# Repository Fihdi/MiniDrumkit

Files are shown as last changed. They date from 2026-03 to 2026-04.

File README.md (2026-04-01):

# 30hp Drumkit module
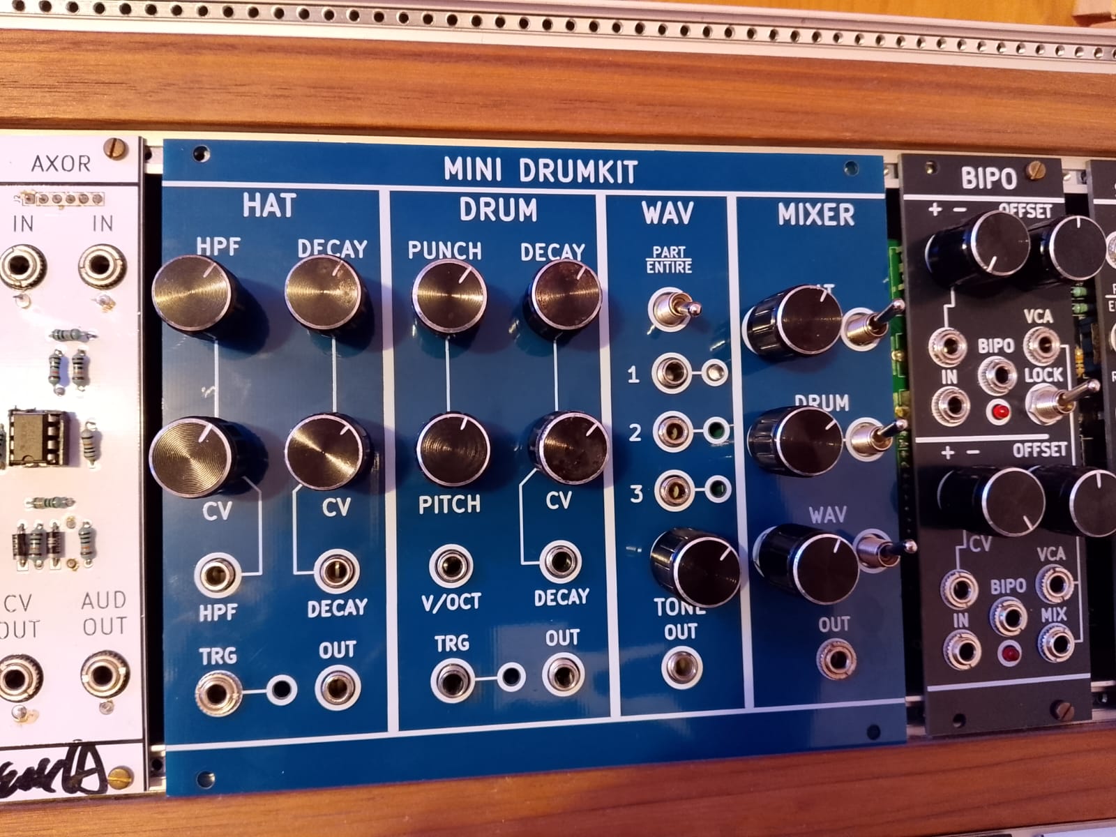
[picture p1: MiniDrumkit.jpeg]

Eurorack DrumKit module with an Arduino Nano ESP32 3 channel wave-file player and analog Hi-Hat and Kick Drum sections.

The WAV Files are read from a microSD card and need to be called "1.wav", "2.wav" and "3.wav". The files need to be mono, encoded in 16-bit and have 16kHz sampling rate. You can use Audacity to export wav files in this format.

Demo Video: https://www.youtube.com/watch?v=cPHg9nKNO_o

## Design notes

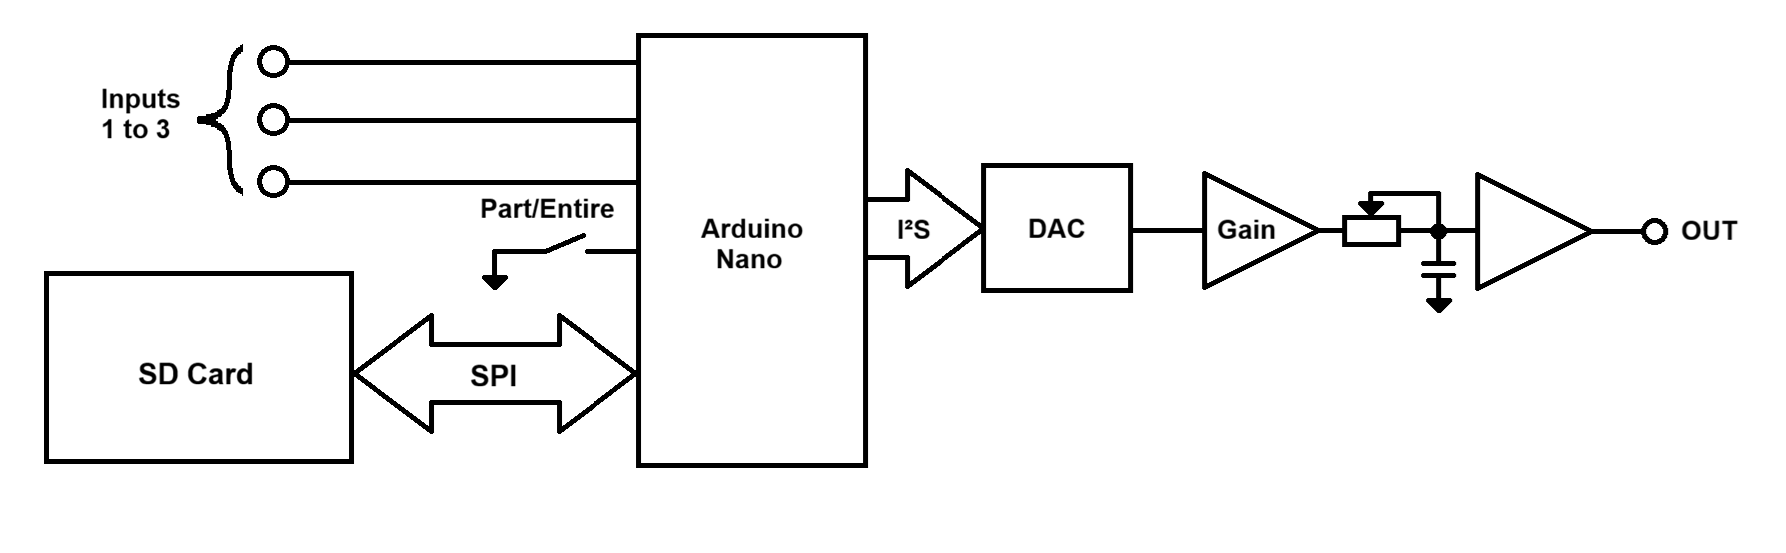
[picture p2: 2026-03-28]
MiniDrumkit2/WAVPlayer-BLOCK.png

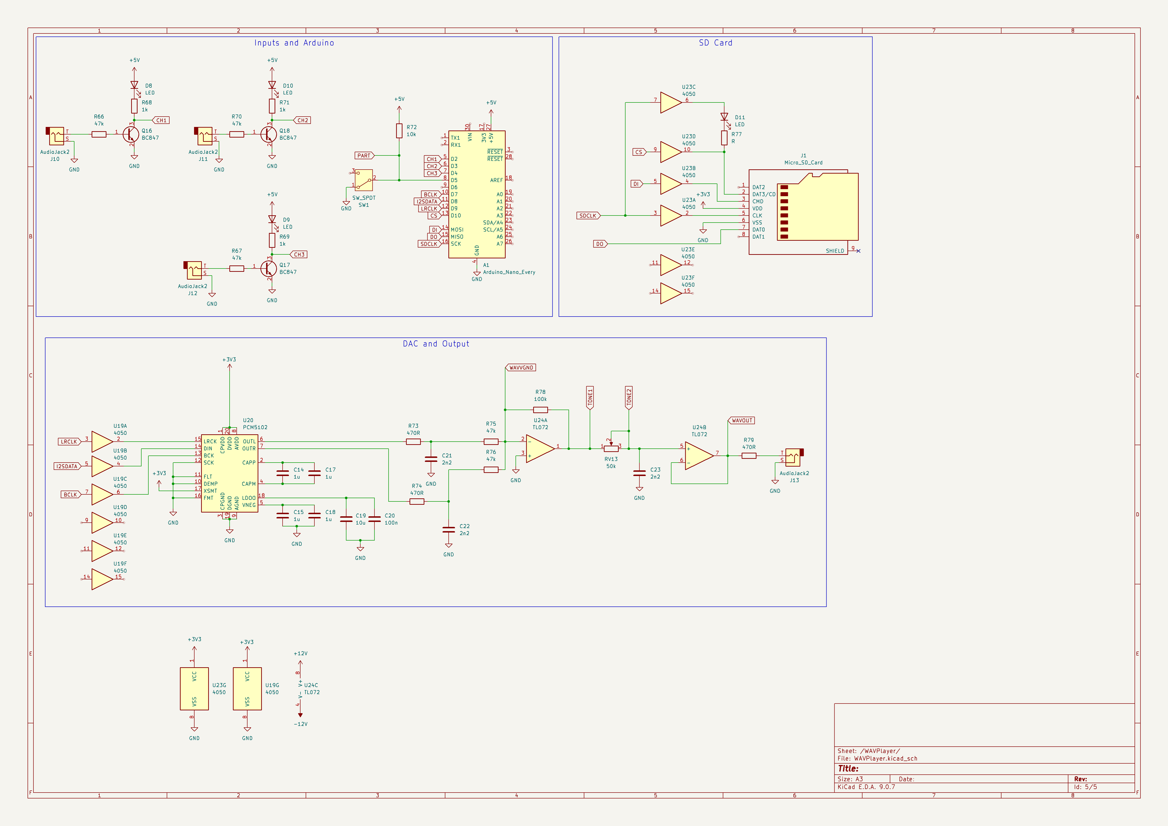
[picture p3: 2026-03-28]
MiniDrumkit2/DAC.png

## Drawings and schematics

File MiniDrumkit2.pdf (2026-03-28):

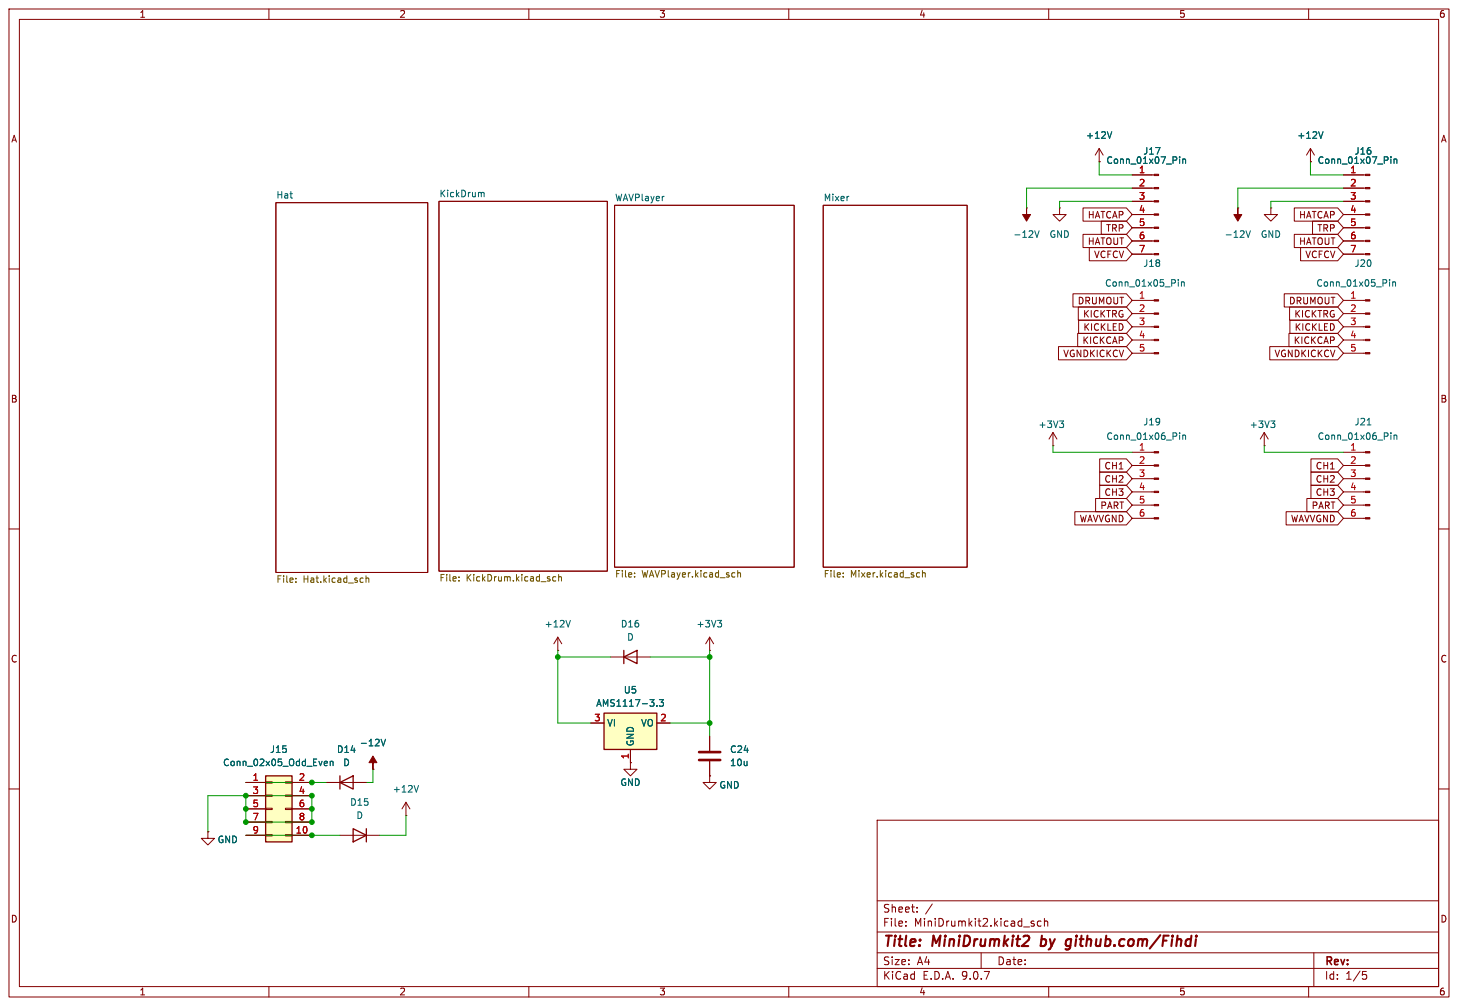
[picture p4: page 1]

5 5 | 6 6
7 7 | 8 8

Id: 1/5 Title: MiniDrumkit2 by github.com/Fihdi File: MiniDrumkit2.kicad_sch Sheet: /

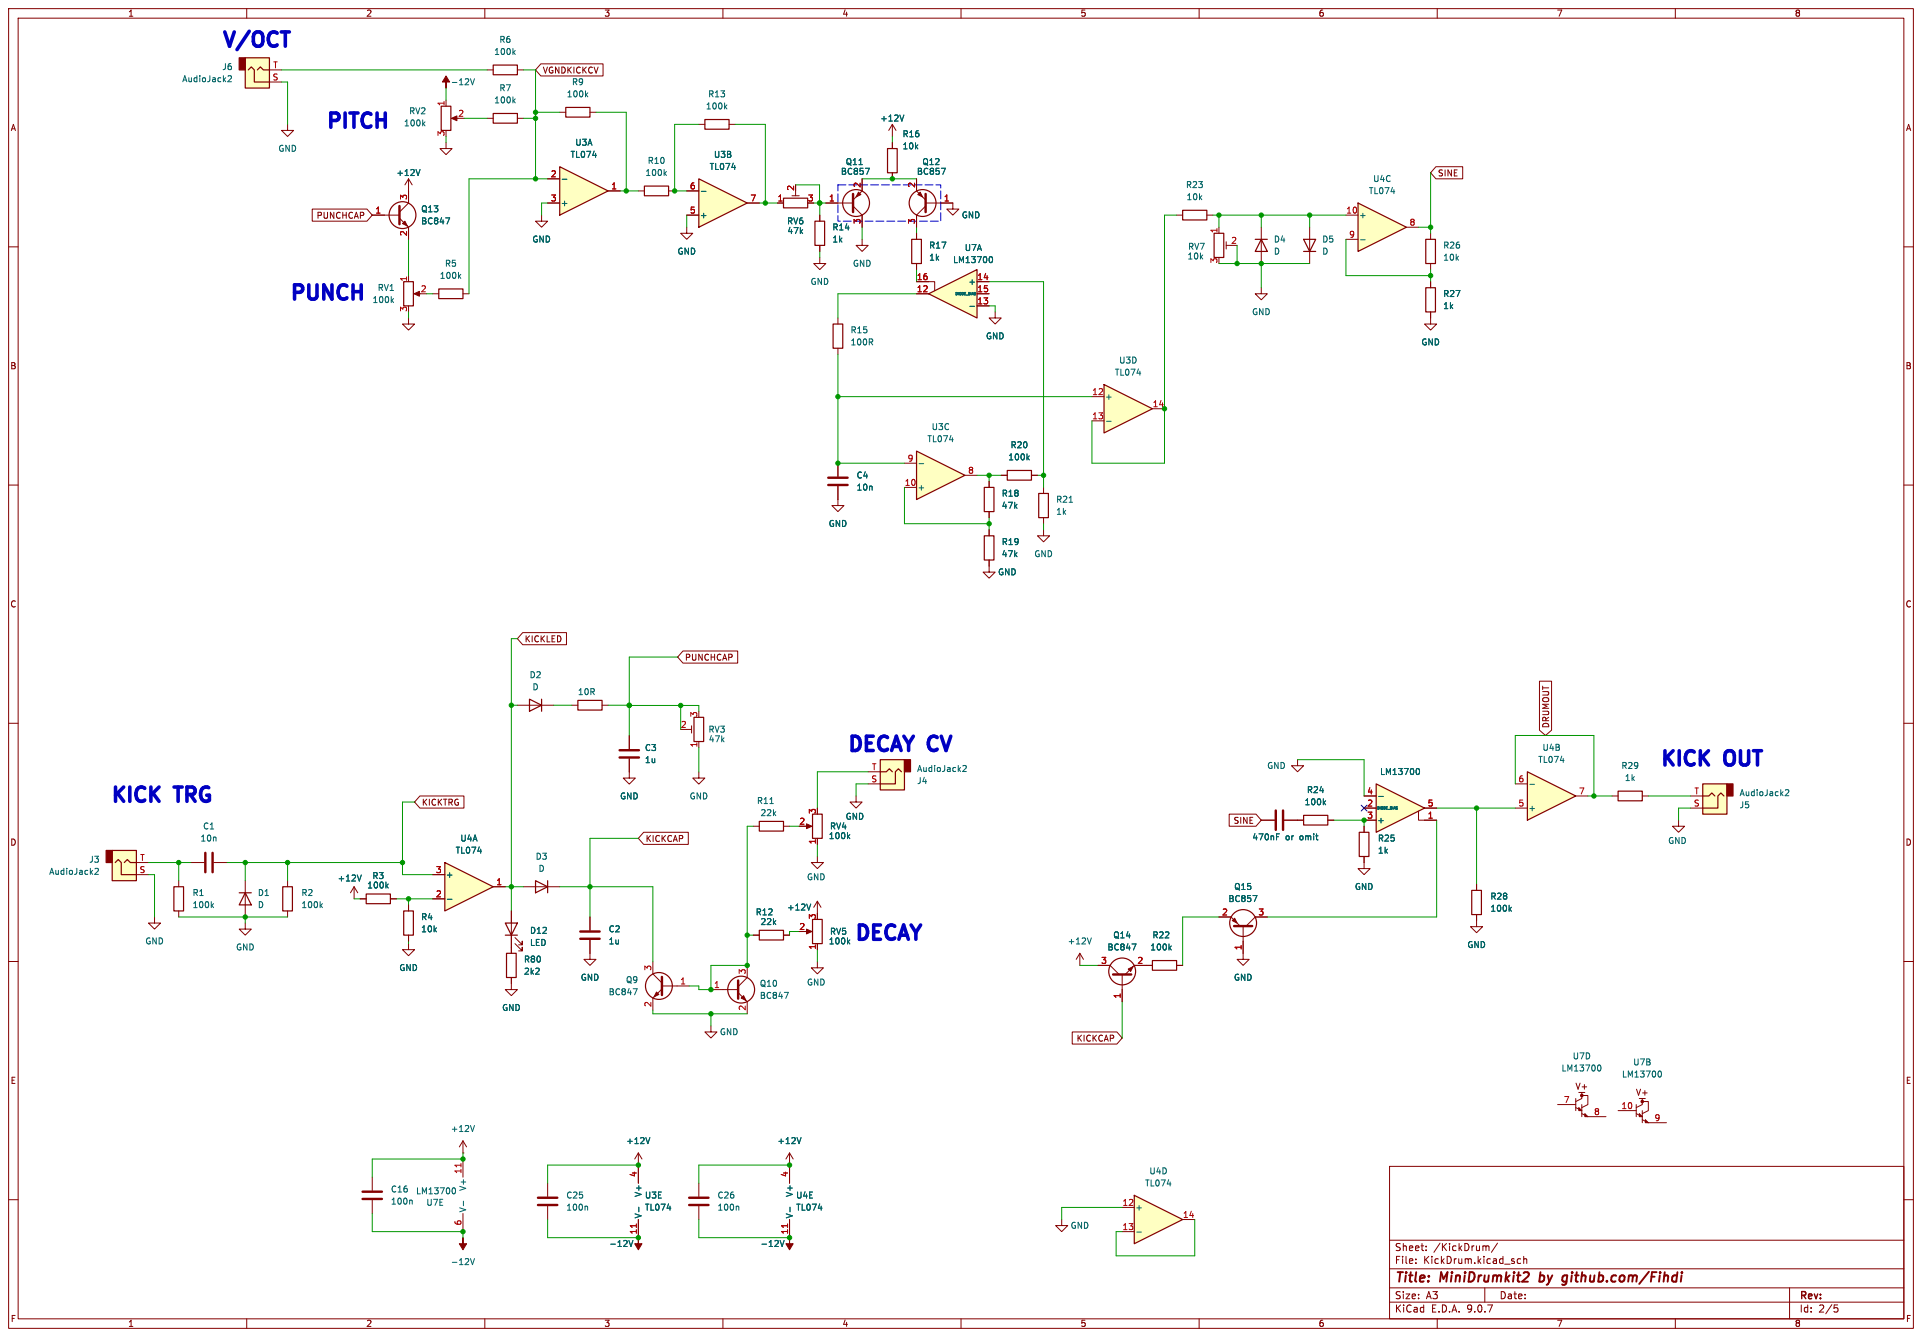
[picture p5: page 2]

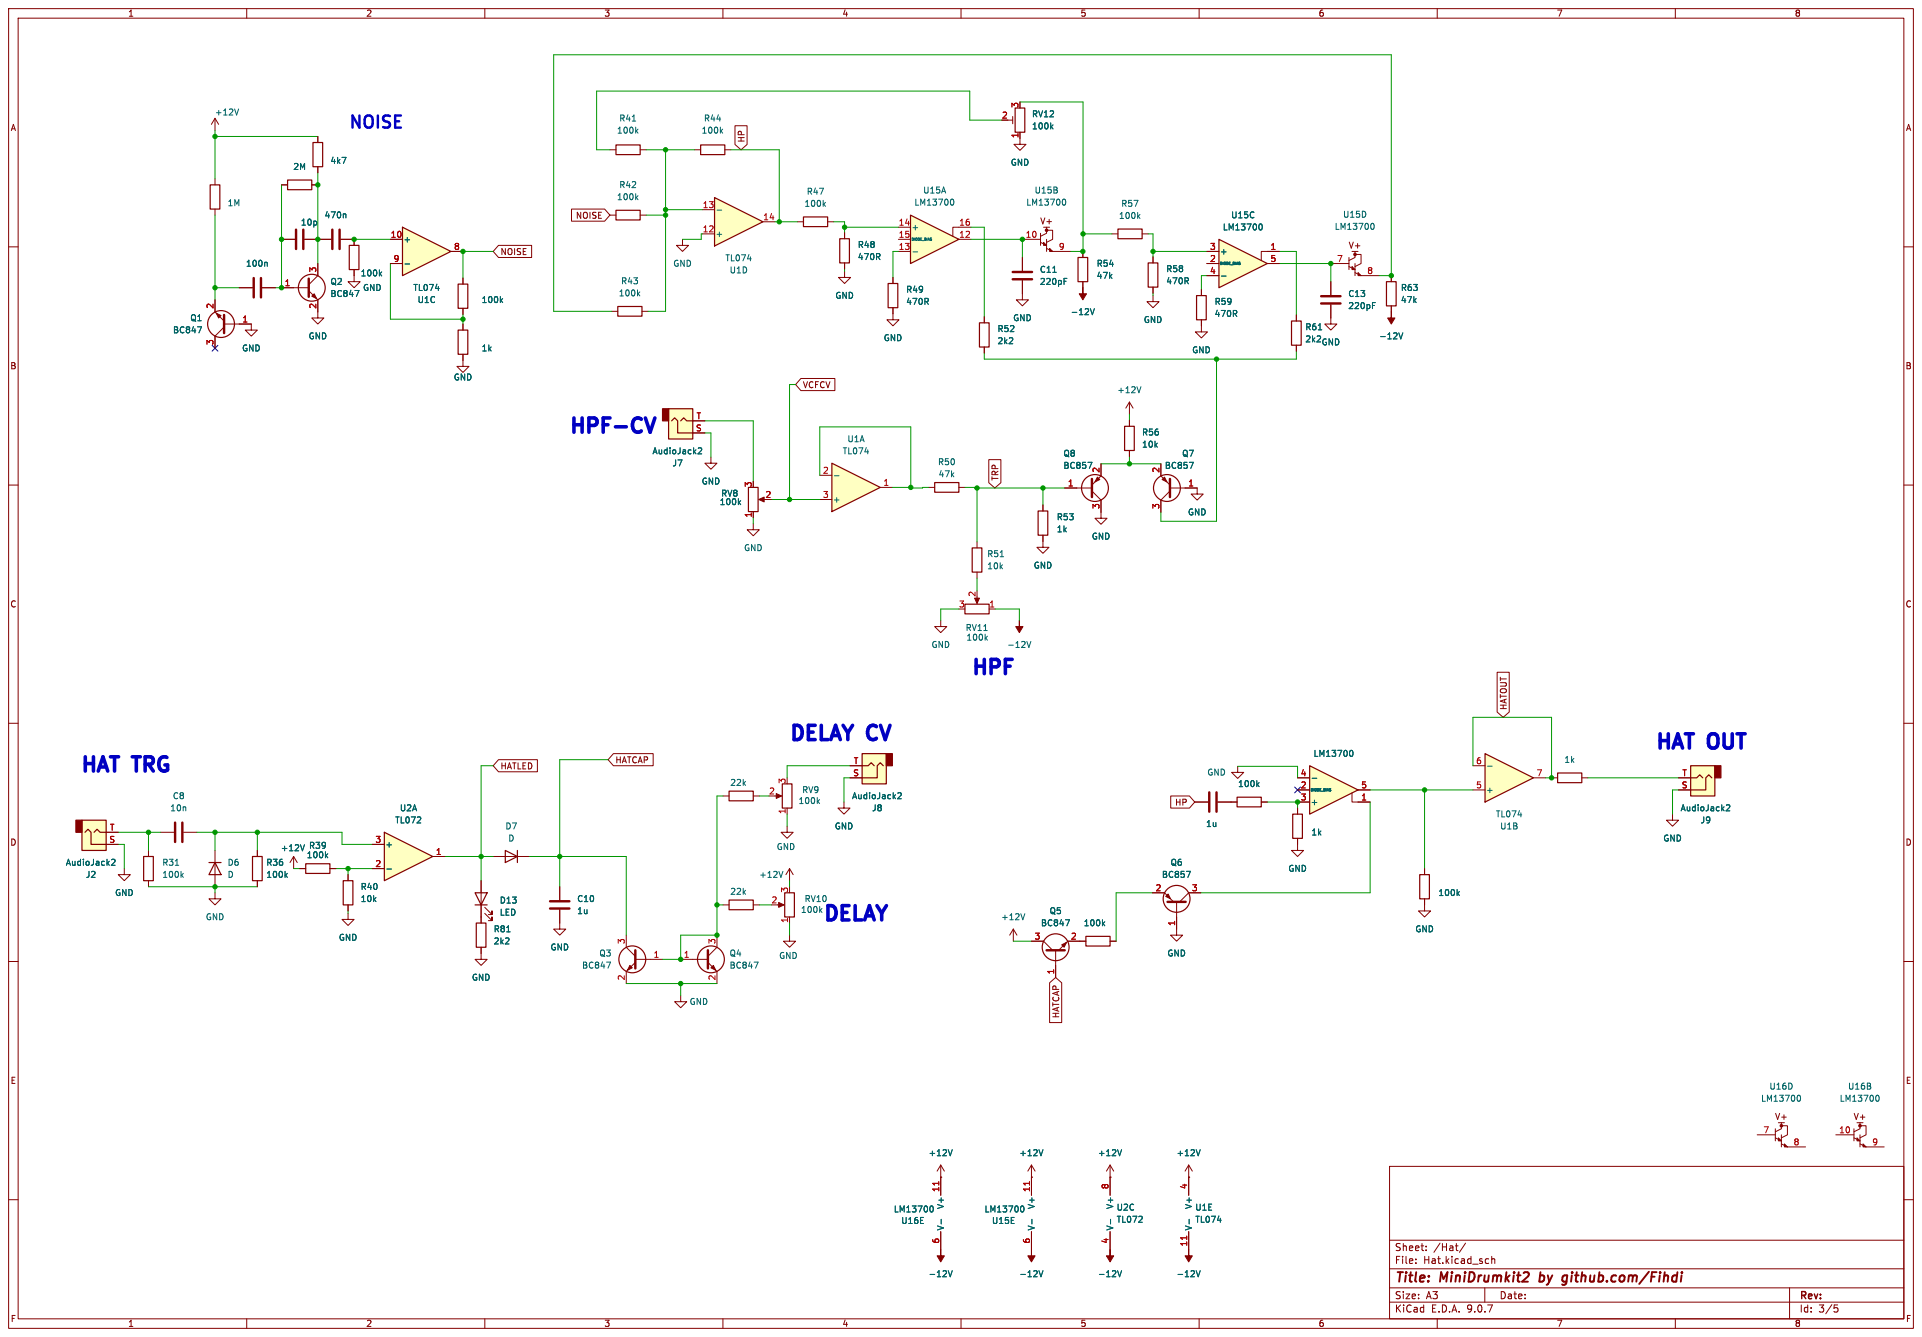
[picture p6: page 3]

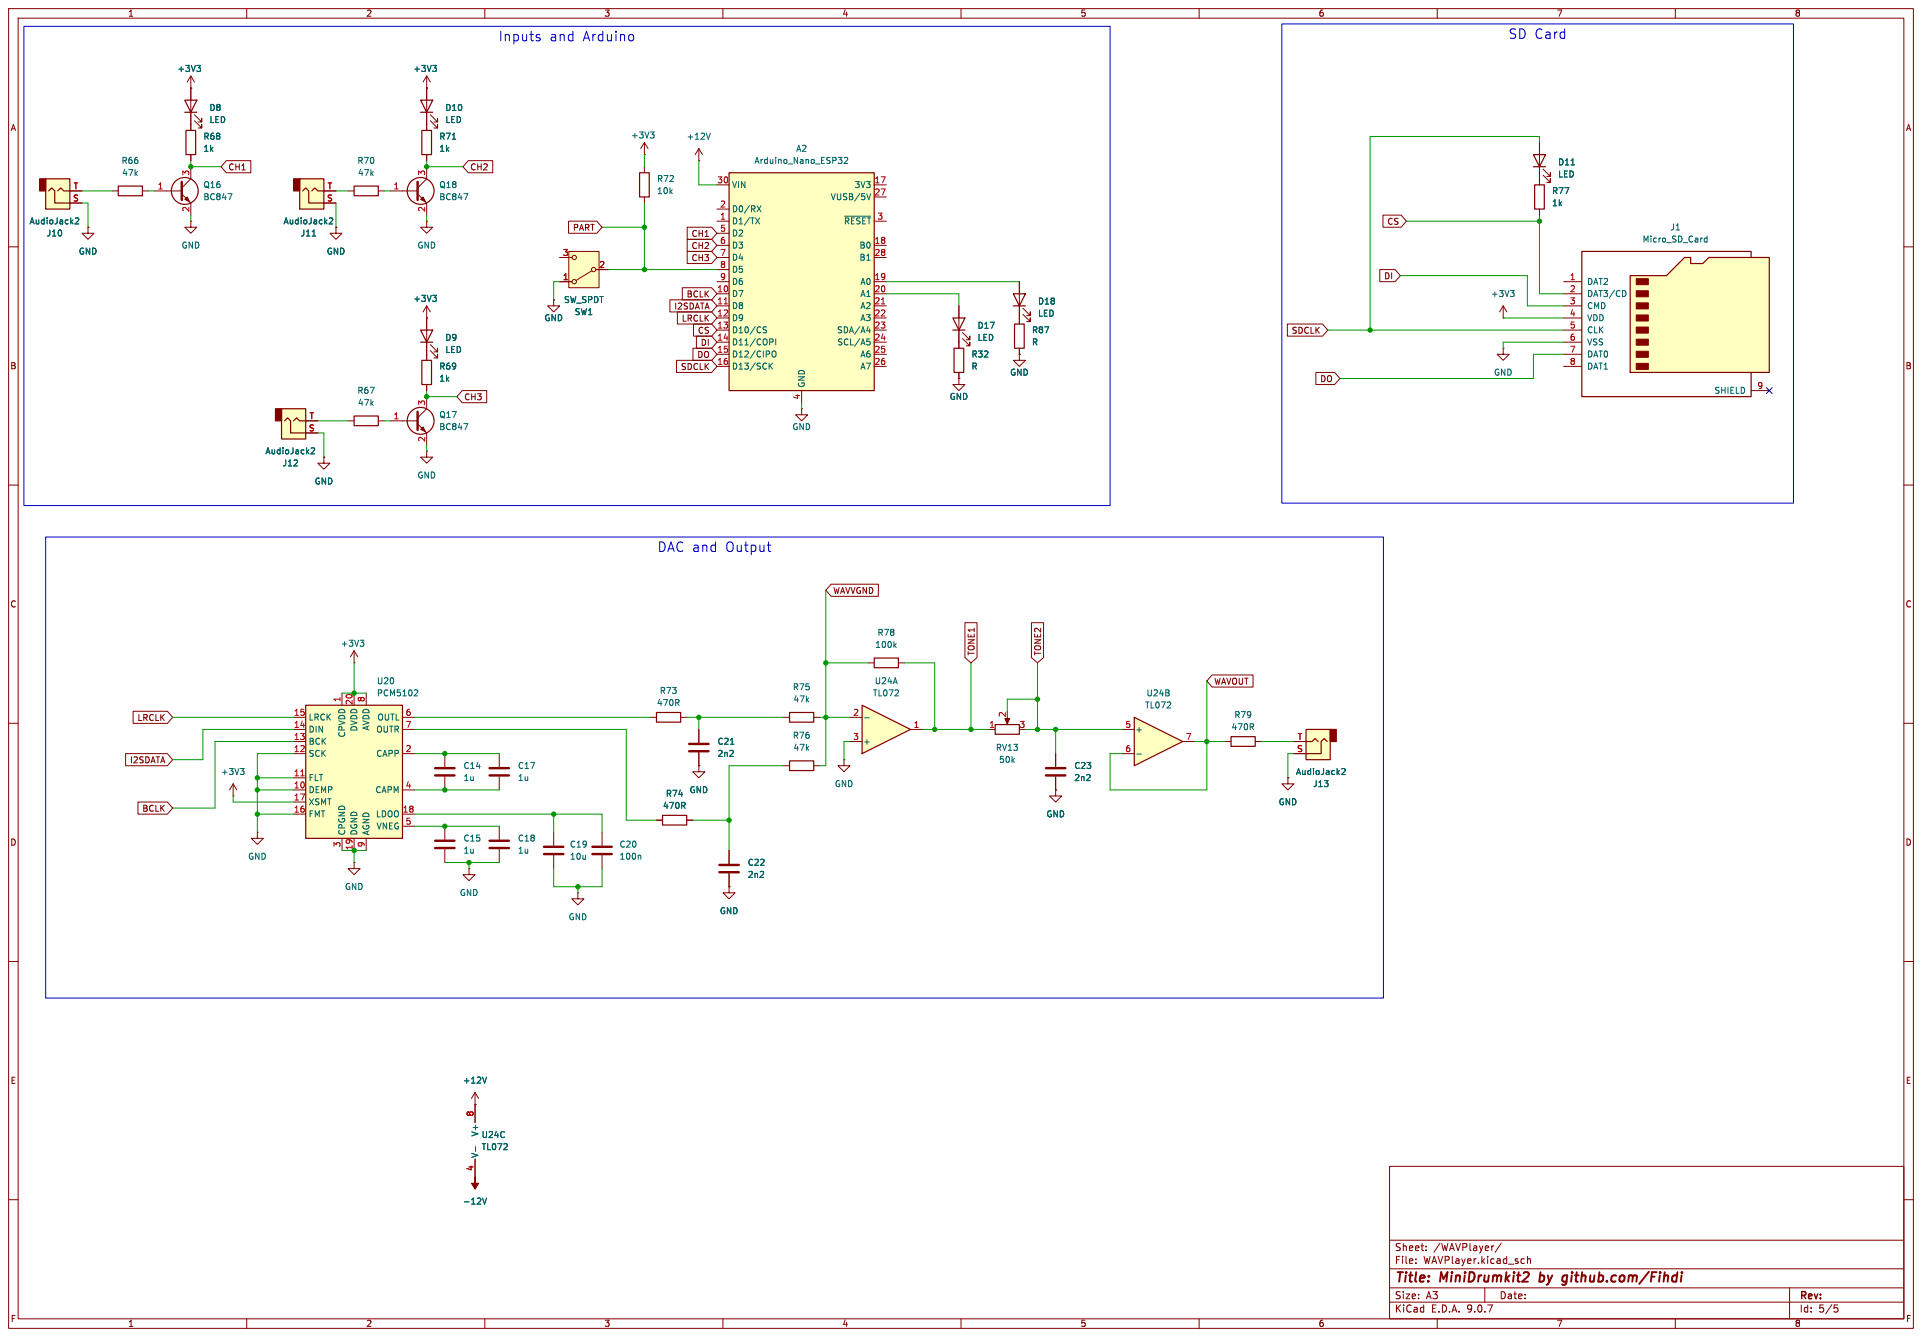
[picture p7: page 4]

9 OUTL 6 OUTR 7 CAPP 2 CAPM 4

Id: 5/5 Title: MiniDrumkit2 by github.com/Fihdi File: WAVPlayer.kicad_sch Sheet: /WAVPlayer/

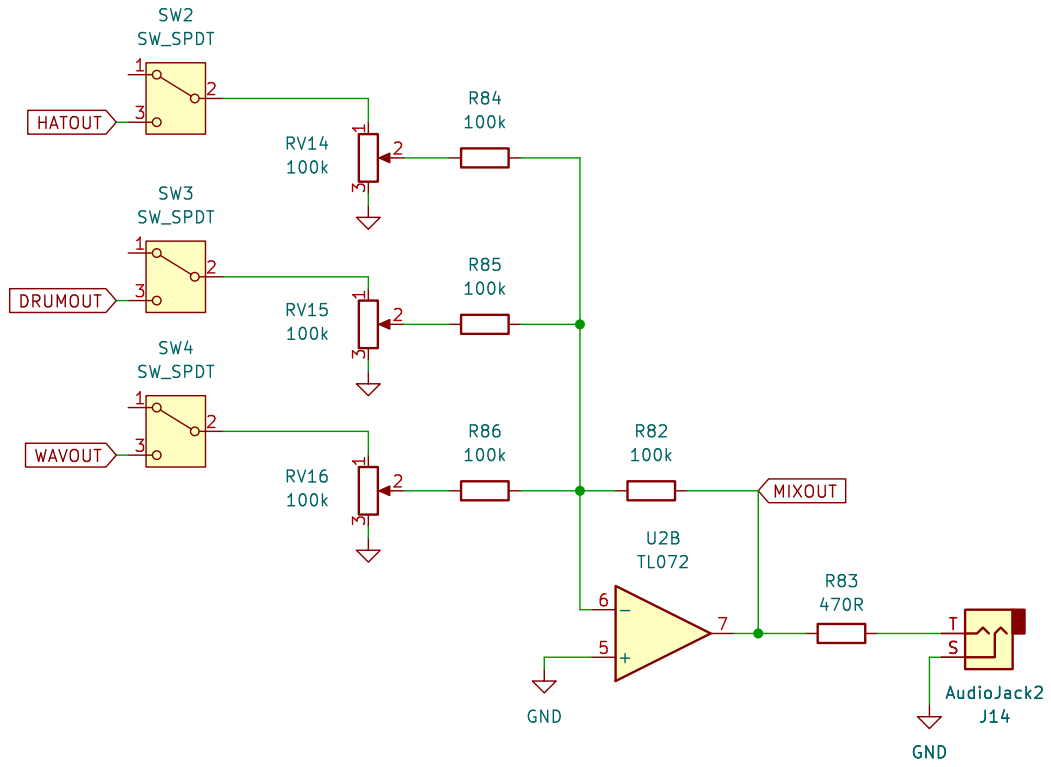
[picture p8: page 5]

Id: 5/5 Title: MiniDrumkit2 by github.com/Fihdi File: Mixer.kicad_sch Sheet: /Mixer/

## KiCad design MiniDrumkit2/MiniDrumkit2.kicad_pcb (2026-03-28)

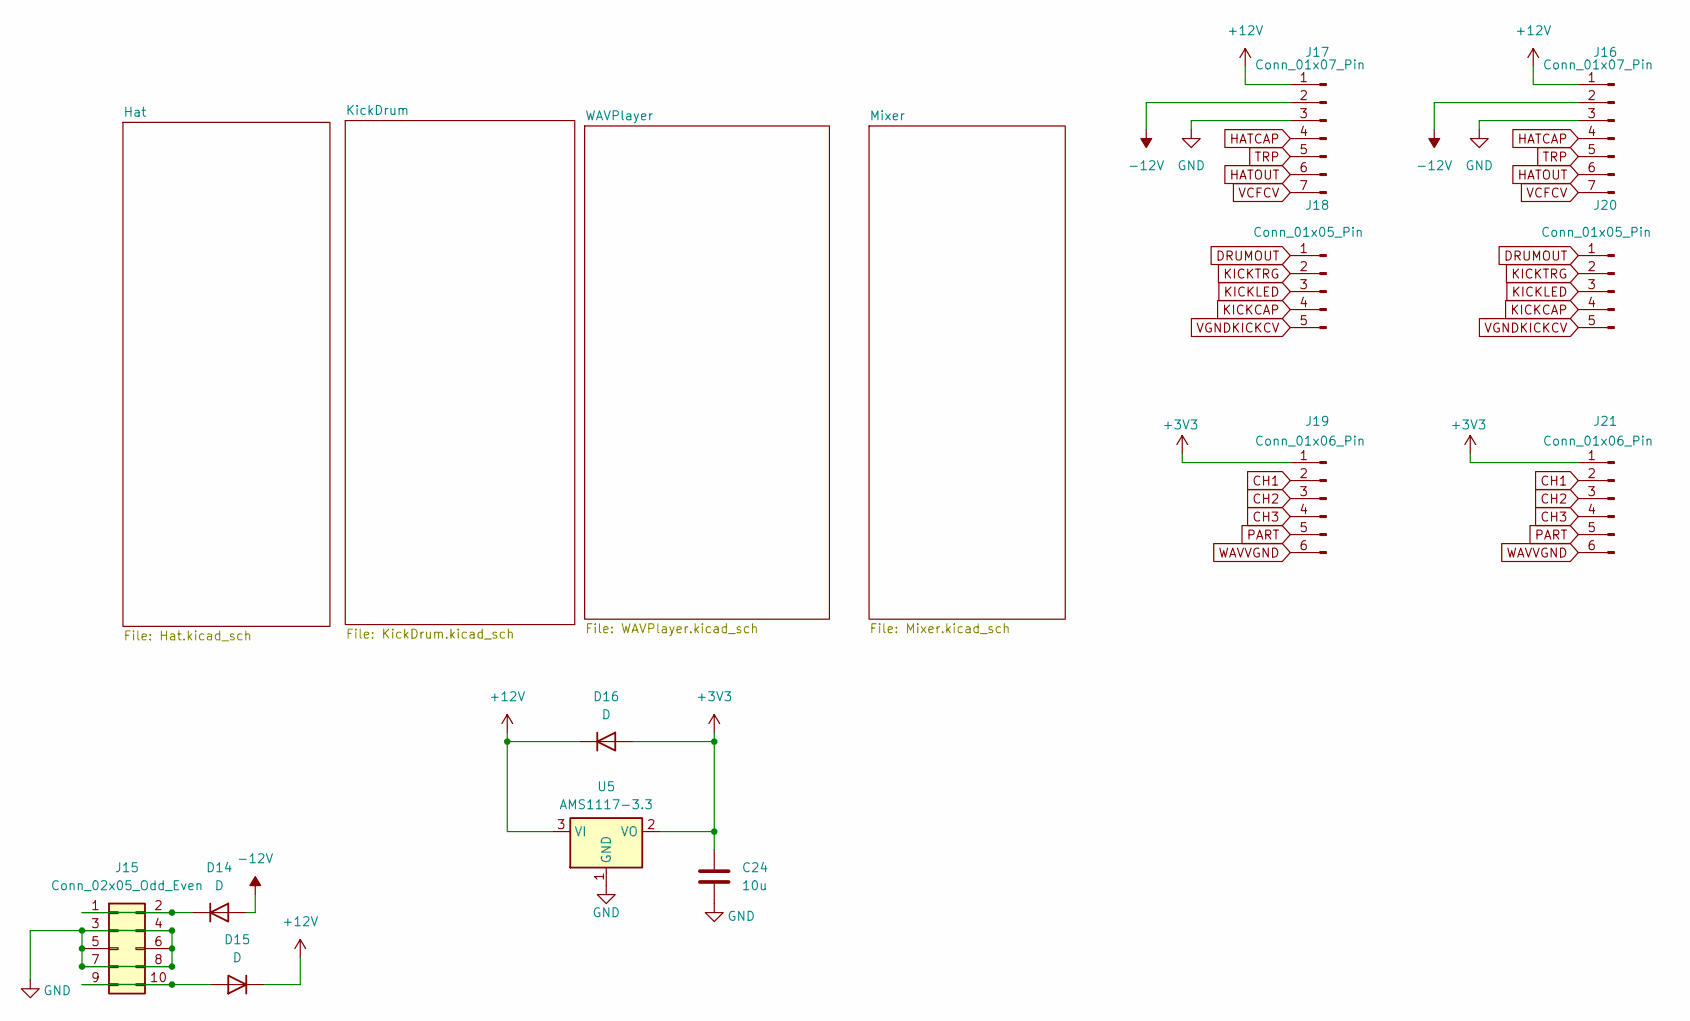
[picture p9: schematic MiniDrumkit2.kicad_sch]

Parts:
C24: 10u; C_1206_3216Metric
D14, D15, D16: D; D_1206_3216Metric_Pad1.42x1.75mm_HandSolder
J15: Conn_02x05_Odd_Even; IDC-Header_2x05_P2.54mm_Vertical
J16, J17: Conn_01x07_Pin; PinHeader_1x07_P2.54mm_Vertical
J18, J20: Conn_01x05_Pin; PinHeader_1x05_P2.54mm_Vertical
J19, J21: Conn_01x06_Pin; PinSocket_1x06_P2.54mm_Vertical
U5: AMS1117-3.3; SOT-223-3_TabPin2

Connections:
+3V3: C24.1, D16.2 (A), J19.1, J21.1, U5.2 (VO); also elsewhere on the board
+12V: D15.1 (K), D16.1 (K), J16.1, J17.1, U5.3 (VI); also elsewhere on the board
-12V: D14.2 (A), J16.2, J17.2; also elsewhere on the board
CH1: J19.2, J21.2; also elsewhere on the board
CH2: J19.3, J21.3; also elsewhere on the board
CH3: J19.4, J21.4; also elsewhere on the board
DRUMOUT: J18.1, J20.1; also elsewhere on the board
GND: C24.2, J15.3, J15.4, J15.5, J15.6, J15.7, J15.8, J16.3, J17.3, U5.1 (GND); also elsewhere on the board
HATCAP: J16.4, J17.4; also elsewhere on the board
HATOUT: J16.6, J17.6; also elsewhere on the board
KICKCAP: J18.4, J20.4; also elsewhere on the board
KICKLED: J18.3, J20.3; also elsewhere on the board
KICKTRG: J18.2, J20.2; also elsewhere on the board
unnamed: D14.1 (K), J15.1, J15.2
unnamed: D15.2 (A), J15.9, J15.10
PART: J19.5, J21.5; also elsewhere on the board
TRP: J16.5, J17.5; also elsewhere on the board
VCFCV: J16.7, J17.7; also elsewhere on the board
VGNDKICKCV: J18.5, J20.5; also elsewhere on the board
WAVVGND: J19.6, J21.6; also elsewhere on the board

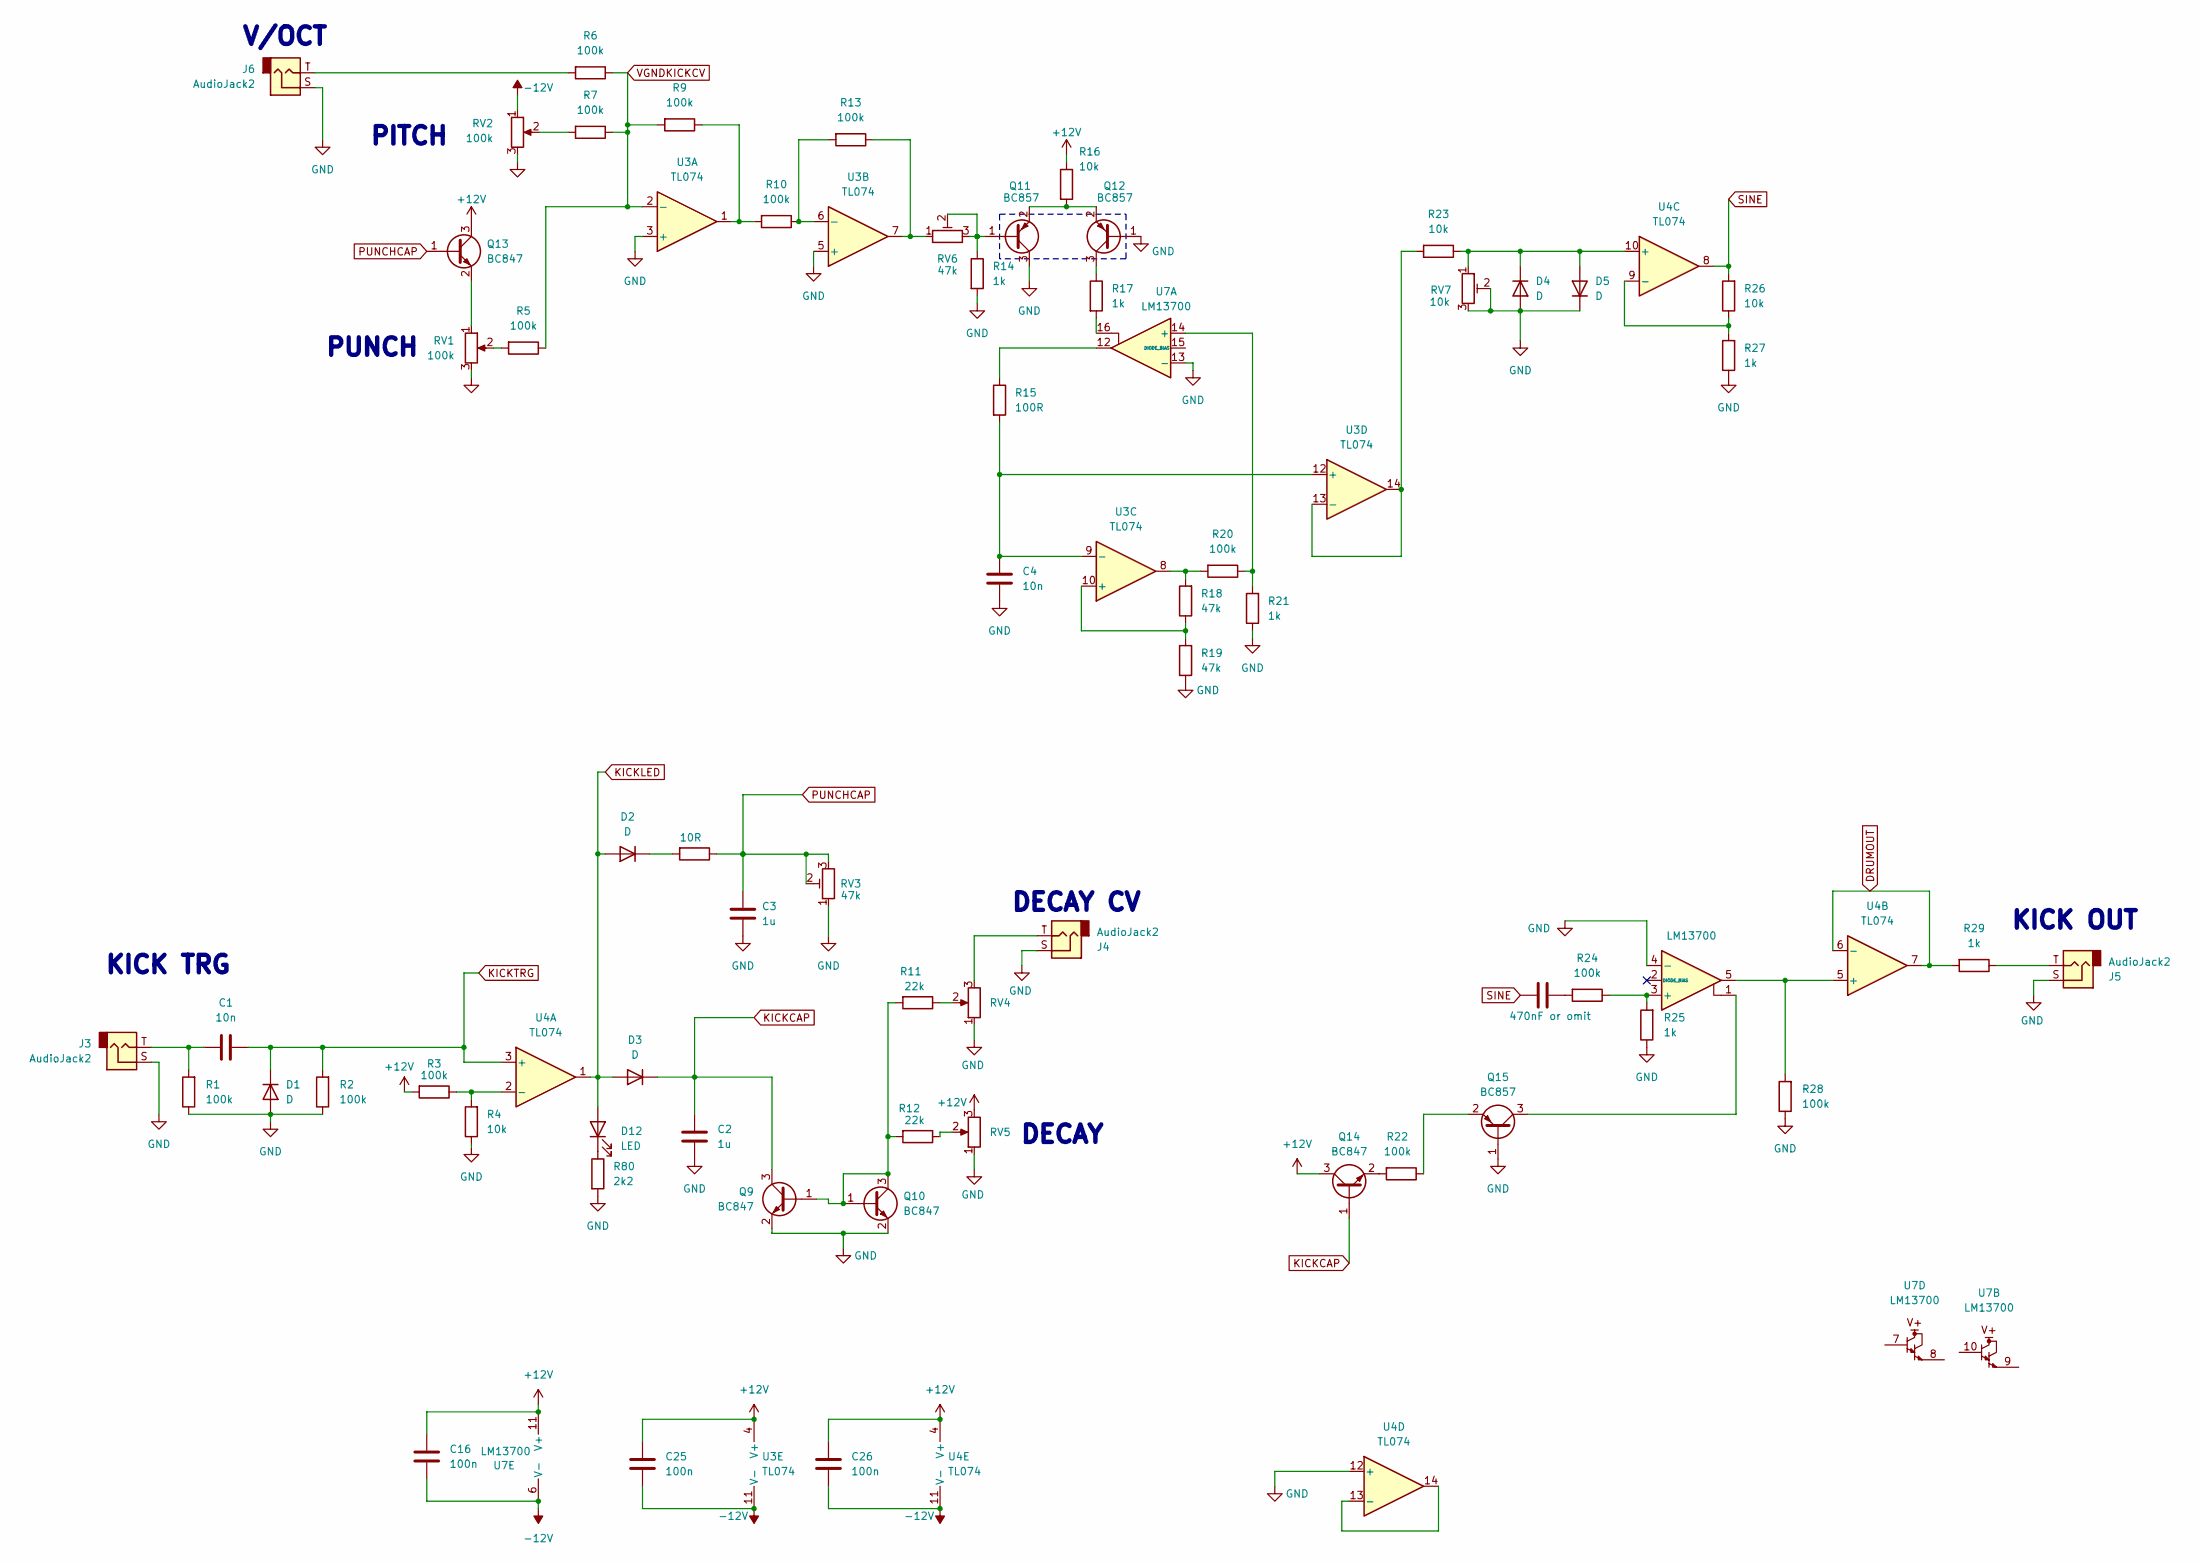
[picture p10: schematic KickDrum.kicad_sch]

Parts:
C1, C4: 10n; C_1206_3216Metric
C2, C3: 1u; C_1206_3216Metric
C5: 470nF or omit; C_1206_3216Metric
C16, C25, C26: 100n; C_1206_3216Metric
D1, D2, D3, D4, D5: D; D_1206_3216Metric
D12: LED; LED_D3.0mm
J3, J4, J5, J6: AudioJack2; MonoTRS
Q9, Q10, Q13, Q14: BC847; SOT-23
Q11, Q12, Q15: BC857; SOT-23
R1, R2, R3, R5, R6, R7, R9, R10, R13, R20, R22, R24, R28: 100k; R_1206_3216Metric
R4, R16, R23, R26: 10k; R_1206_3216Metric
R8: 10R; R_1206_3216Metric
R11, R12: 22k; R_1206_3216Metric
R14, R17, R21, R25, R27, R29: 1k; R_1206_3216Metric
R15: 100R; R_1206_3216Metric
R18, R19: 47k; R_1206_3216Metric
R80: 2k2; R_1206_3216Metric
RV1, RV2: 100k; Potentiometer_Alpha_RD901F-40-00D_Single_Vertical_CircularH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
RV3, RV6: 47k; Potentiometer_ACP_CA9-H5_Horizontal
RV4, RV5: R_Potentiometer; Potentiometer_Alpha_RD901F-40-00D_Single_Vertical_CircularH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
RV7: 10k; Potentiometer_ACP_CA9-H5_Horizontal
U3, U4: TL074; SOIC-14_3.9x8.7mm_P1.27mm
U7: LM13700; SOIC-16_3.9x9.9mm_P1.27mm

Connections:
+12V: C16.1, C25.1, C26.1, Q13.3 (C), Q14.3 (C), R3.2, R16.1, RV5.3, U3.4 (V+), U4.4 (V+), U7.11 (V+); also elsewhere on the board
-12V: C16.2, C25.2, C26.2, RV2.1, U3.11 (V-), U4.11 (V-), U7.6 (V-); also elsewhere on the board
DRUMOUT: R29.2, U4.6 (-), U4.7; also elsewhere on the board
GND: C2.2, C3.2, C4.2, D1.2 (A), D4.2 (A), D5.1 (K), J3.S, J4.S, J5.S, J6.S, Q9.2 (E), Q10.2 (E), Q11.3 (C), Q12.1 (B), Q15.1 (B), R1.1, R2.1, R4.1, R14.2, R19.1, R21.1, R25.1, R27.1, R28.1, R80.2, RV1.3, RV2.3, RV3.1, RV4.1, RV5.1, RV7.2, RV7.3, U3.3 (+), U3.5 (+), U4.12 (+), U7.4 (-), U7.13 (-); also elsewhere on the board
KICKCAP: C2.1, D3.1 (K), Q9.3 (C), Q14.1 (B); also elsewhere on the board
KICKLED: D2.2 (A), D3.2 (A), D12.2 (A), U4.1; also elsewhere on the board
KICKTRG: C1.2, D1.1 (K), R2.2, U4.3 (+); also elsewhere on the board
unnamed: C1.1, J3.T, R1.2
unnamed: C5.2, R24.2
unnamed: D2.1 (K), R8.2
unnamed: D4.1 (K), D5.2 (A), R23.1, RV7.1, U4.10 (+)
unnamed: D12.1 (K), R80.1
unnamed: J4.T, RV4.3
unnamed: J5.T, R29.1
unnamed: J6.T, R6.2
unnamed: Q9.1 (B), Q10.1 (B), Q10.3 (C), R11.2, R12.2
unnamed: Q11.1 (B), R14.1, RV6.2, RV6.3
unnamed: Q11.2 (E), Q12.2 (E), R16.2
unnamed: Q12.3 (C), R17.1
unnamed: Q13.2 (E), RV1.1
unnamed: Q14.2 (E), R22.2
unnamed: Q15.3 (C), U7.1
unnamed: Q15.2 (E), R22.1
unnamed: R5.2, RV1.2
unnamed: R7.2, RV2.2
unnamed: R9.1, R10.2, U3.1
unnamed: R11.1, RV4.2
unnamed: R12.1, RV5.2
unnamed: R13.1, RV6.1, U3.7
unnamed: R15.1, U7.12
unnamed: R17.2, U7.16
unnamed: R18.2, R20.2, U3.8
unnamed: R10.1, R13.2, U3.6 (-)
unnamed: R18.1, R19.2, U3.10 (+)
unnamed: C4.1, R15.2, U3.9 (-), U3.12 (+)
unnamed: R23.2, U3.13 (-), U3.14
unnamed: R3.1, R4.2, U4.2 (-)
unnamed: R28.2, U4.5 (+), U7.5
unnamed: R26.1, R27.2, U4.9 (-)
unnamed: U4.13 (-), U4.14
unnamed: R20.1, R21.2, U7.14 (+)
unnamed: R24.1, R25.2, U7.3 (+)
PUNCHCAP: C3.1, Q13.1 (B), R8.1, RV3.2, RV3.3
SINE: C5.1, R26.2, U4.8
VGNDKICKCV: R5.1, R6.1, R7.1, R9.2, U3.2 (-); also elsewhere on the board

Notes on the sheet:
DECAY CV
KICK OUT
PITCH
V/OCT
DECAY
KICK TRG
PUNCH

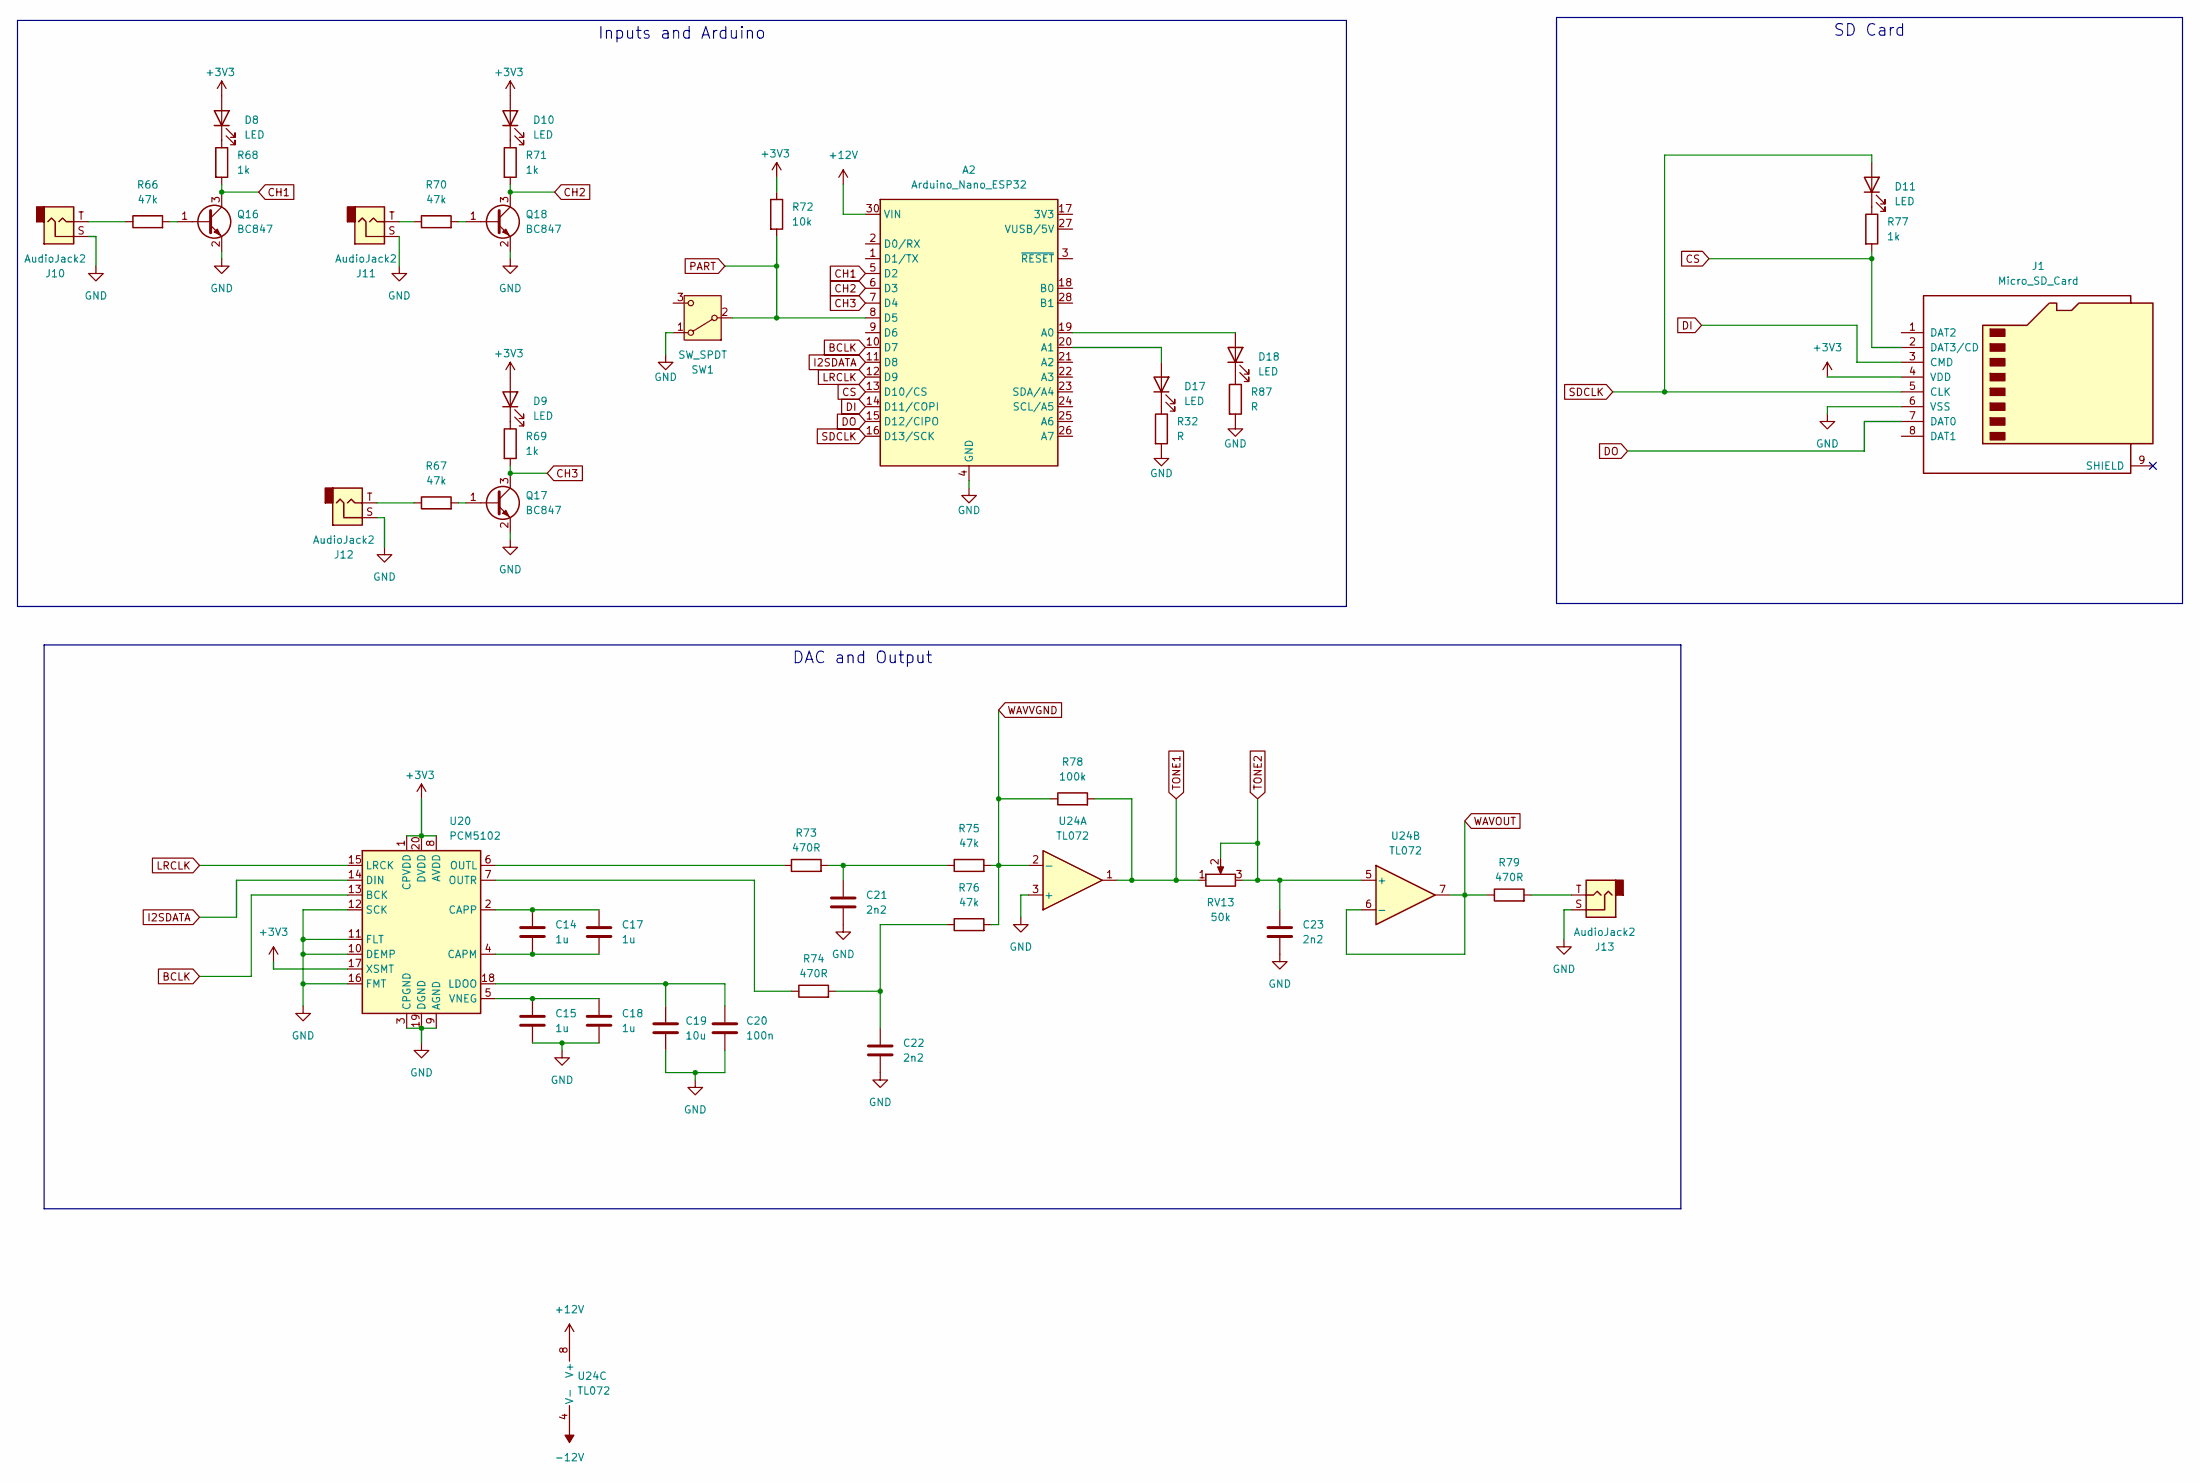
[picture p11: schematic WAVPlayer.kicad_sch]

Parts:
A2: Arduino_Nano_ESP32; Arduino_Nano
C14, C15, C17, C18: 1u; C_1206_3216Metric
C19: 10u; C_1206_3216Metric
C20: 100n; C_1206_3216Metric
C21, C22, C23: 2n2; C_1206_3216Metric
D8, D9, D10, D11, D17, D18: LED; LED_D3.0mm
J1: Micro_SD_Card; microSD_HC_Molex_47219-2001
J10, J11, J12, J13: AudioJack2; MonoTRS
Q16, Q17, Q18: BC847; SOT-23
R32, R87: R; R_1206_3216Metric
R66, R67, R70, R75, R76: 47k; R_1206_3216Metric
R68, R69, R71, R77: 1k; R_1206_3216Metric
R72: 10k; R_1206_3216Metric
R73, R74, R79: 470R; R_1206_3216Metric
R78: 100k; R_1206_3216Metric
RV13: 50k; Potentiometer_Alpha_RD901F-40-00D_Single_Vertical_CircularH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
SW1: SW_SPDT; Switch
U20: PCM5102; TSSOP-20_4.4x6.5mm_P0.65mm
U24: TL072; SOIC-8_3.9x4.9mm_P1.27mm

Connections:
+3V3: D8.2 (A), D9.2 (A), D10.2 (A), J1.4 (VDD), R72.1, U20.1 (CPVDD), U20.8 (AVDD), U20.17 (XSMT), U20.20 (DVDD); also elsewhere on the board
+12V: A2.30 (VIN), U24.8 (V+); also elsewhere on the board
-12V: U24.4 (V-); also elsewhere on the board
BCLK: A2.10 (D7), U20.13 (BCK)
CH1: A2.5 (D2), Q16.3 (C), R68.2; also elsewhere on the board
CH2: A2.6 (D3), Q18.3 (C), R71.2; also elsewhere on the board
CH3: A2.7 (D4), Q17.3 (C), R69.2; also elsewhere on the board
CS: A2.13 (D10/CS), J1.2 (DAT3/CD), R77.2
DI: A2.14 (D11/COPI), J1.3 (CMD)
DO: A2.15 (D12/CIPO), J1.7 (DAT0)
GND: A2.4 (GND), A2.29 (GND), C15.2, C18.2, C19.2, C20.2, C21.2, C22.2, C23.2, J1.6 (VSS), J10.S, J11.S, J12.S, J13.S, Q16.2 (E), Q17.2 (E), Q18.2 (E), R32.2, R87.2, SW1.1 (A), U20.3 (CPGND), U20.9 (AGND), U20.10 (DEMP), U20.11 (FLT), U20.12 (SCK), U20.16 (FMT), U20.19 (DGND), U24.3 (+); also elsewhere on the board
I2SDATA: A2.11 (D8), U20.14 (DIN)
LRCLK: A2.12 (D9), U20.15 (LRCK)
unnamed: A2.19 (A0), D18.2 (A)
unnamed: A2.20 (A1), D17.2 (A)
unnamed: C21.1, R73.2, R75.1
unnamed: C22.1, R74.2, R76.1
unnamed: D8.1 (K), R68.1
unnamed: D9.1 (K), R69.1
unnamed: D10.1 (K), R71.1
unnamed: D11.1 (K), R77.1
unnamed: D17.1 (K), R32.1
unnamed: D18.1 (K), R87.1
unnamed: J10.T, R66.1
unnamed: J11.T, R70.1
unnamed: J12.T, R67.1
unnamed: J13.T, R79.2
unnamed: Q16.1 (B), R66.2
unnamed: Q17.1 (B), R67.2
unnamed: Q18.1 (B), R70.2
unnamed: C14.2, C17.2, U20.4 (CAPM)
unnamed: C14.1, C17.1, U20.2 (CAPP)
unnamed: C19.1, C20.1, U20.18 (LDOO)
unnamed: R73.1, U20.6 (OUTL)
unnamed: R74.1, U20.7 (OUTR)
unnamed: C15.1, C18.1, U20.5 (VNEG)
PART: A2.8 (D5), R72.2, SW1.2 (B); also elsewhere on the board
SDCLK: A2.16 (D13/SCK), D11.2 (A), J1.5 (CLK)
TONE1: R78.2, RV13.1, U24.1
TONE2: C23.1, RV13.2, RV13.3, U24.5 (+)
WAVOUT: R79.1, U24.6 (-), U24.7; also elsewhere on the board
WAVVGND: R75.2, R76.2, R78.1, U24.2 (-); also elsewhere on the board

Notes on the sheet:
DAC and Output
SD Card
Inputs and Arduino

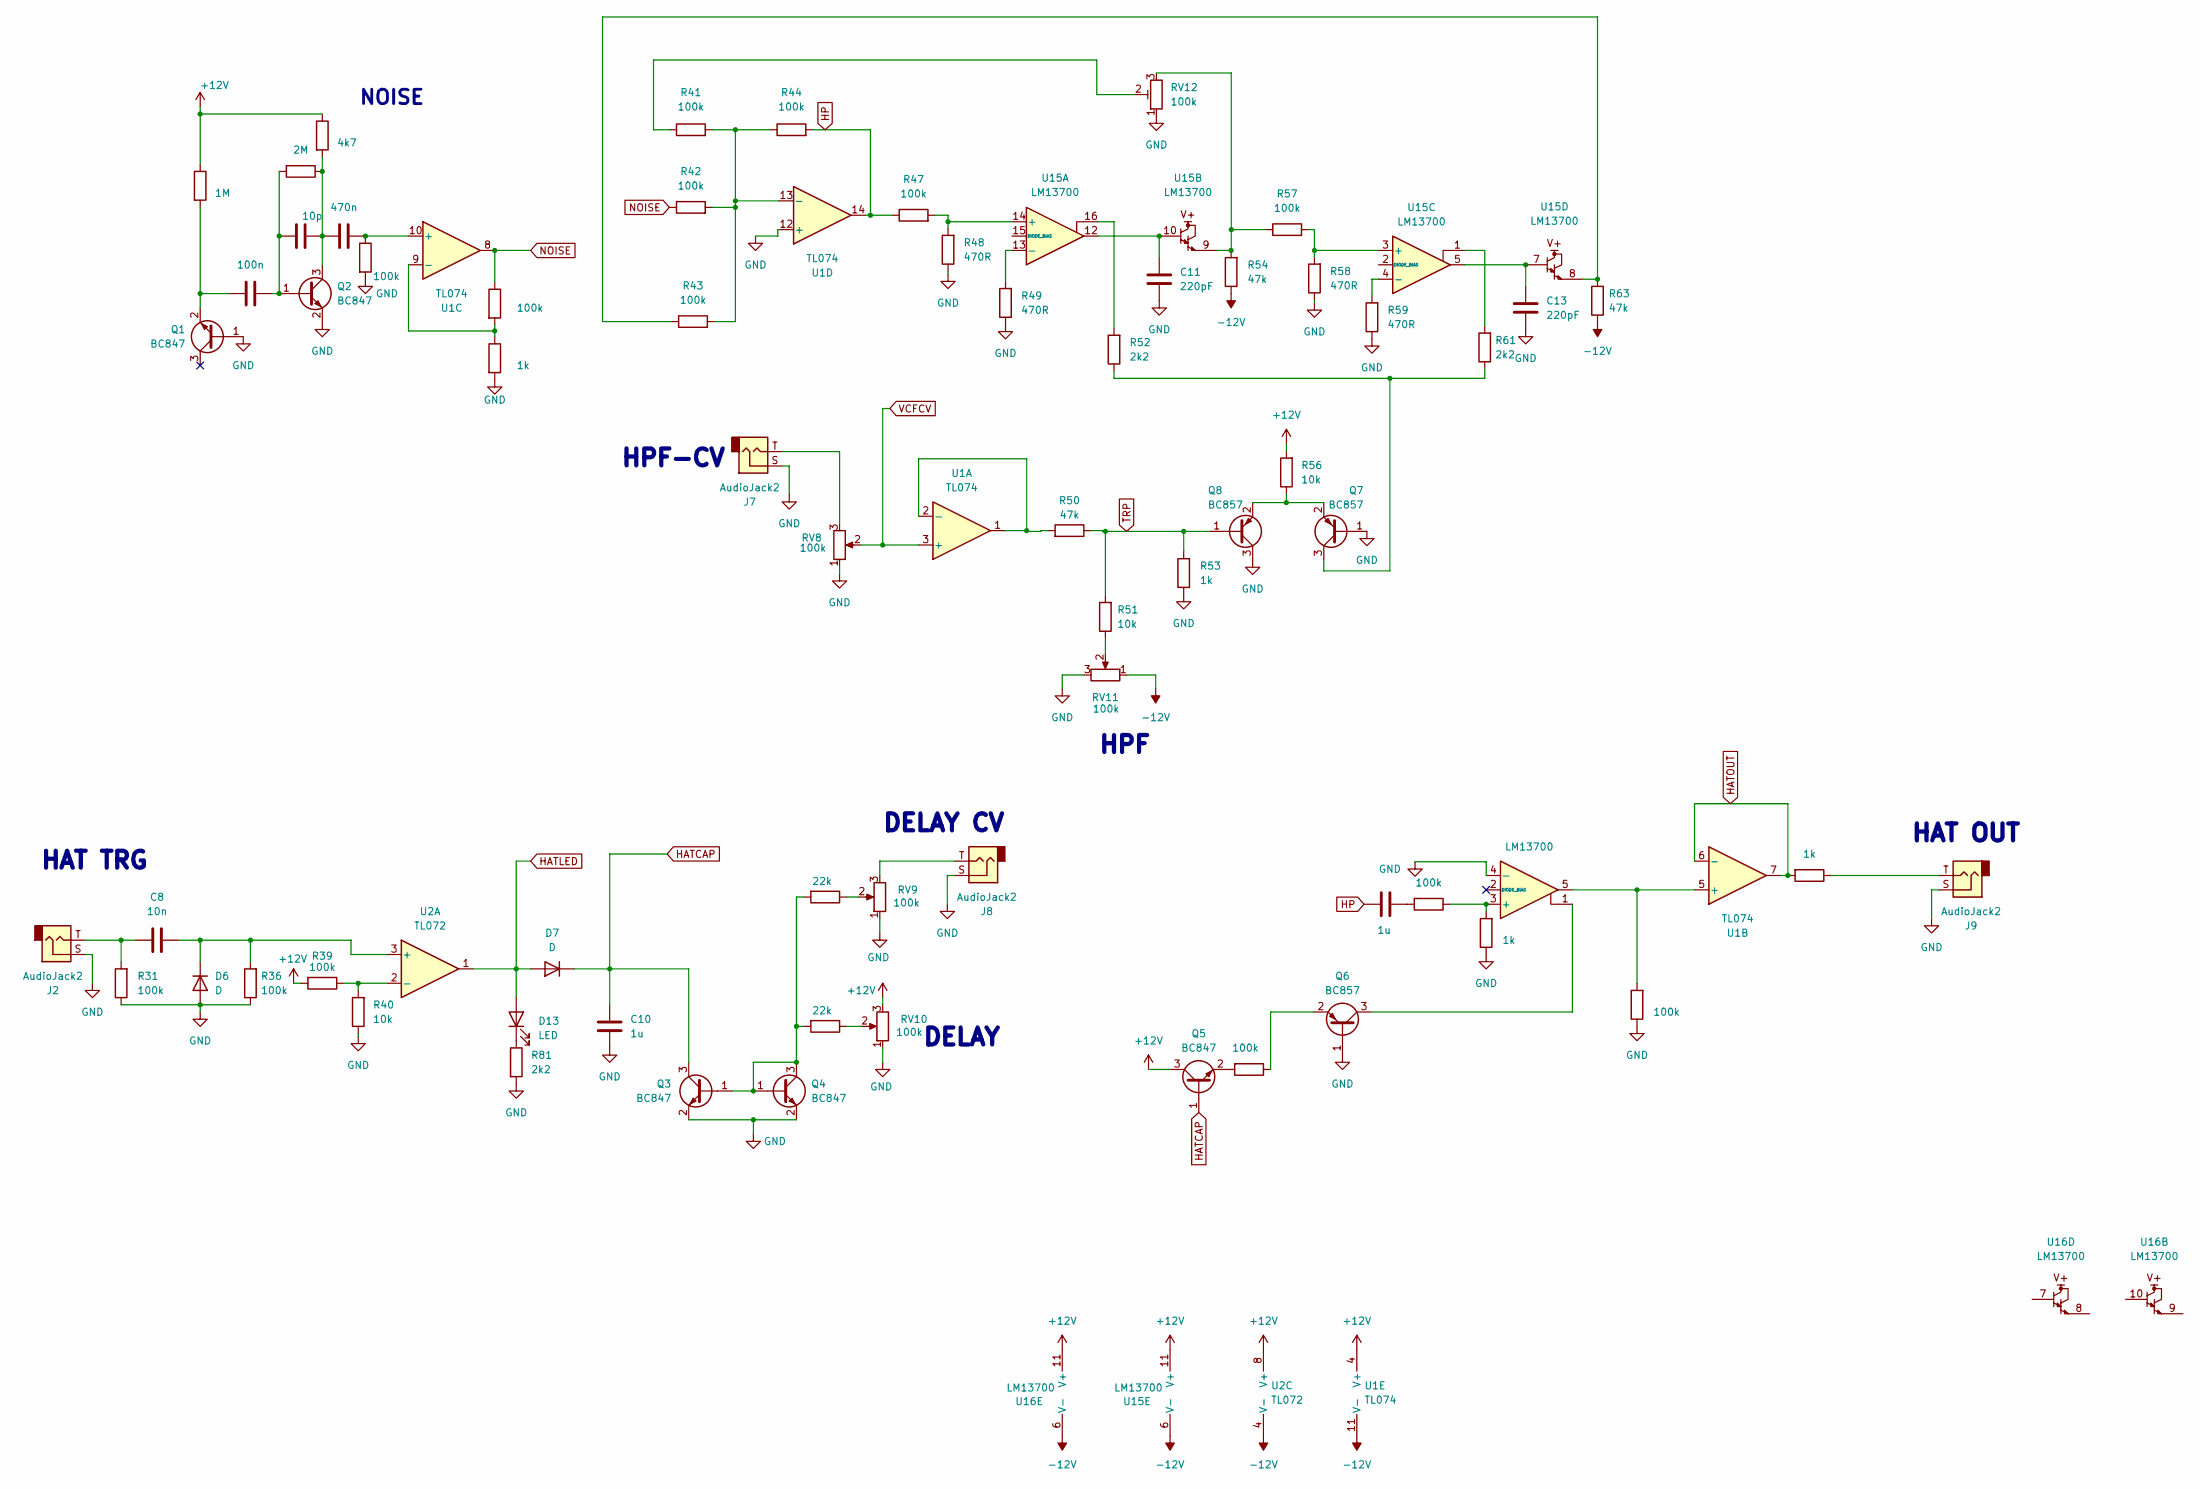
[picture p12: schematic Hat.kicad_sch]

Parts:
C6: 100n; C_1206_3216Metric
C7: 10p; C_1206_3216Metric
C8: 10n; C_1206_3216Metric
C9: 470n; C_1206_3216Metric
C10, C12: 1u; C_1206_3216Metric
C11, C13: 220pF; C_1206_3216Metric
D6, D7: D; D_1206_3216Metric
D13: LED; LED_D3.0mm
J2, J7, J8, J9: AudioJack2; MonoTRS
Q1, Q2, Q3, Q4, Q5: BC847; SOT-23
Q6, Q7, Q8: BC857; SOT-23
R30: 1M; R_1206_3216Metric
R31, R35, R36, R37, R39, R41, R42, R43, R44, R47, R55, R57, R60, R64: 100k; R_1206_3216Metric
R33: 2M; R_1206_3216Metric
R34: 4k7; R_1206_3216Metric
R38, R53, R62, R65: 1k; R_1206_3216Metric
R40, R51, R56: 10k; R_1206_3216Metric
R45, R46: 22k; R_1206_3216Metric
R48, R49, R58, R59: 470R; R_1206_3216Metric
R50, R54, R63: 47k; R_1206_3216Metric
R52, R61, R81: 2k2; R_1206_3216Metric
RV8, RV9, RV10, RV11: 100k; Potentiometer_Alpha_RD901F-40-00D_Single_Vertical_CircularH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
RV12: 100k; Potentiometer_ACP_CA9-H5_Horizontal
U1: TL074; SOIC-14_3.9x8.7mm_P1.27mm
U2: TL072; SOIC-8_5.3x6.2mm_P1.27mm
U15, U16: LM13700; SOIC-16_3.9x9.9mm_P1.27mm

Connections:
+12V: Q5.3 (C), R30.1, R34.1, R39.2, R56.2, RV10.3, U1.4 (V+), U2.8 (V+), U15.11 (V+), U16.11 (V+); also elsewhere on the board
-12V: R54.1, R63.1, RV11.1, U1.11 (V-), U2.4 (V-), U15.6 (V-), U16.6 (V-); also elsewhere on the board
GND: C10.2, C11.2, C13.2, D6.2 (A), J2.S, J7.S, J8.S, J9.S, Q1.1 (B), Q2.2 (E), Q3.2 (E), Q4.2 (E), Q6.1 (B), Q7.1 (B), Q8.3 (C), R31.1, R35.2, R36.1, R38.2, R40.1, R48.1, R49.1, R53.1, R58.1, R59.1, R62.1, R64.1, R81.2, RV8.1, RV9.1, RV10.1, RV11.3, RV12.1, U1.12 (+), U16.4 (-); also elsewhere on the board
HATCAP: C10.1, D7.1 (K), Q3.3 (C), Q5.1 (B); also elsewhere on the board
HATLED: D7.2 (A), D13.2 (A), U2.1
HATOUT: R65.2, U1.6 (-), U1.7; also elsewhere on the board
HP: C12.1, R44.2, R47.1, U1.14
NOISE: R37.1, R42.1, U1.8
unnamed: C8.1, J2.T, R31.2
unnamed: C11.1, U15.10, U15.12
unnamed: C12.2, R60.2
unnamed: C13.1, U15.5, U15.7
unnamed: C8.2, D6.1 (K), R36.2, U2.3 (+)
unnamed: D13.1 (K), R81.1
unnamed: J7.T, RV8.3
unnamed: J8.T, RV9.3
unnamed: J9.T, R65.1
unnamed: C6.1, Q1.2 (E), R30.2
unnamed: C6.2, C7.1, Q2.1 (B), R33.2
unnamed: C7.2, C9.1, Q2.3 (C), R33.1, R34.2
unnamed: Q3.1 (B), Q4.1 (B), Q4.3 (C), R45.2, R46.2
unnamed: Q5.2 (E), R55.2
unnamed: Q6.3 (C), U16.1
unnamed: Q6.2 (E), R55.1
unnamed: Q7.3 (C), R52.1, R61.1
unnamed: Q7.2 (E), Q8.2 (E), R56.1
unnamed: R41.1, RV12.2
unnamed: R43.1, R63.2, U15.8
unnamed: R45.1, RV9.2
unnamed: R46.1, RV10.2
unnamed: R51.1, RV11.2
unnamed: R52.2, U15.16
unnamed: R61.2, U15.1
unnamed: R50.2, U1.1, U1.2 (-)
unnamed: R64.2, U1.5 (+), U16.5
unnamed: C9.2, R35.1, U1.10 (+)
unnamed: R37.2, R38.1, U1.9 (-)
unnamed: R41.2, R42.2, R43.2, R44.1, U1.13 (-)
unnamed: R39.1, R40.2, U2.2 (-)
unnamed: R47.2, R48.2, U15.14 (+)
unnamed: R49.2, U15.13 (-)
unnamed: R57.2, R58.2, U15.3 (+)
unnamed: R59.2, U15.4 (-)
unnamed: R60.1, R62.2, U16.3 (+)
RES: R54.2, R57.1, RV12.3, U15.9
TRP: Q8.1 (B), R50.1, R51.2, R53.2; also elsewhere on the board
VCFCV: RV8.2, U1.3 (+); also elsewhere on the board

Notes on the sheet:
NOISE
HPF-CV
HPF
DELAY CV
DELAY
HAT OUT
HAT TRG

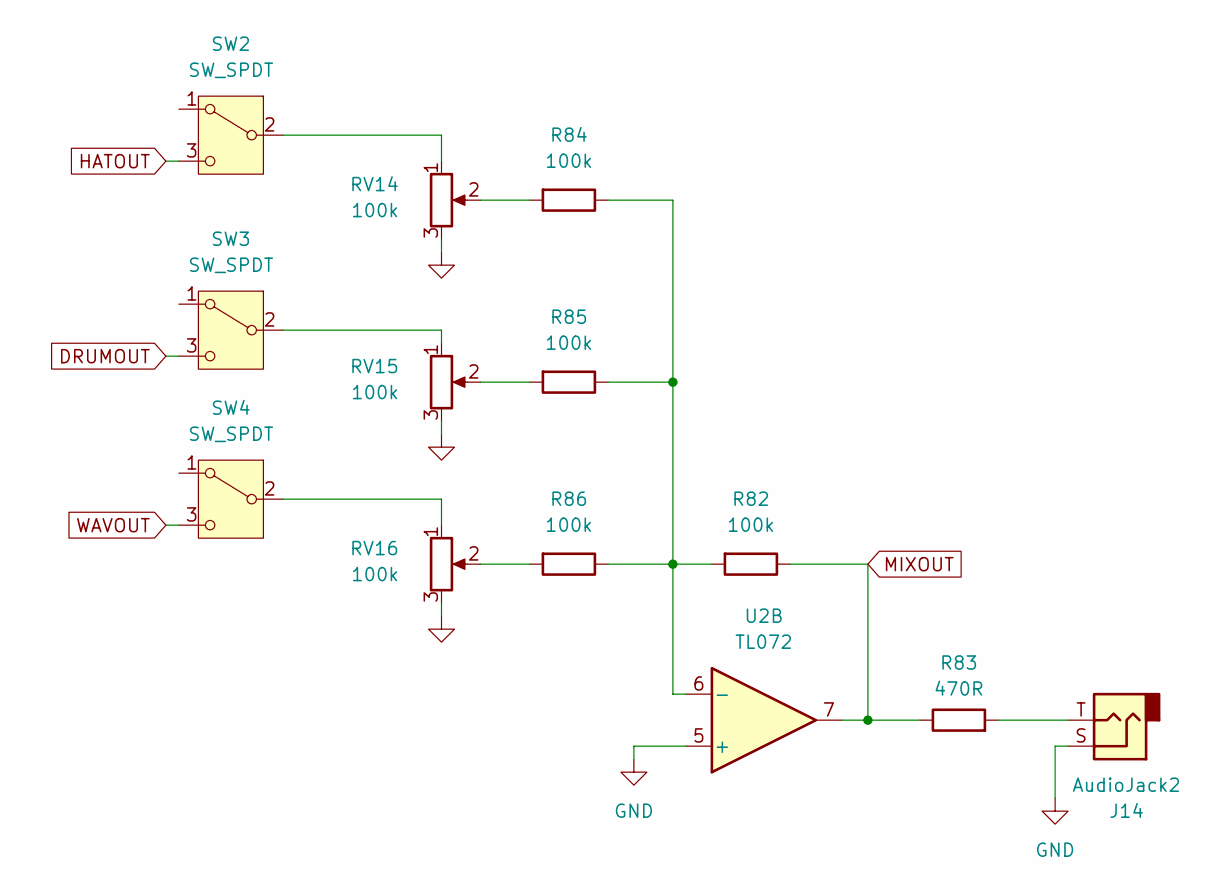
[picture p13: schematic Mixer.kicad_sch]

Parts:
J14: AudioJack2; MonoTRS
R82, R84, R85, R86: 100k; R_1206_3216Metric
R83: 470R; R_1206_3216Metric
RV14, RV15, RV16: 100k; Potentiometer_Alpha_RD901F-40-00D_Single_Vertical_CircularH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
SW2, SW3, SW4: SW_SPDT; Switch
U2: TL072; SOIC-8_5.3x6.2mm_P1.27mm

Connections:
DRUMOUT: SW3.3 (C); also elsewhere on the board
GND: J14.S, RV14.3, RV15.3, RV16.3, U2.5 (+); also elsewhere on the board
HATOUT: SW2.3 (C); also elsewhere on the board
MIXOUT: R82.1, R83.1, U2.7
unnamed: J14.T, R83.2
unnamed: R84.2, RV14.2
unnamed: R85.2, RV15.2
unnamed: R86.2, RV16.2
unnamed: RV14.1, SW2.2 (B)
unnamed: RV15.1, SW3.2 (B)
unnamed: RV16.1, SW4.2 (B)
unnamed: R82.2, R84.1, R85.1, R86.1, U2.6 (-)
WAVOUT: SW4.3 (C); also elsewhere on the board

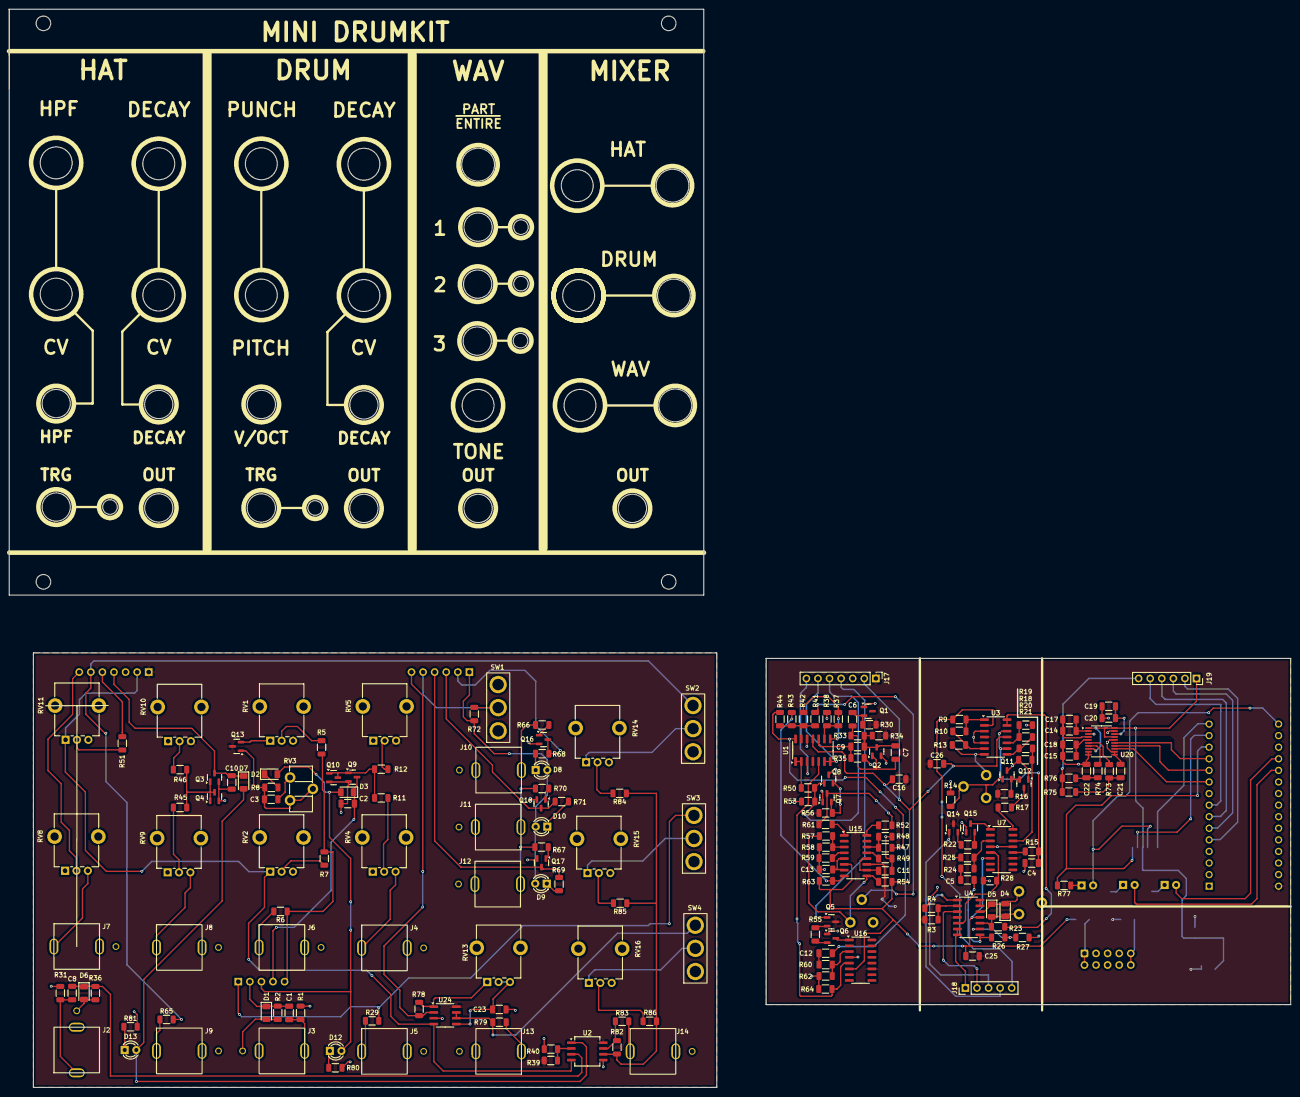
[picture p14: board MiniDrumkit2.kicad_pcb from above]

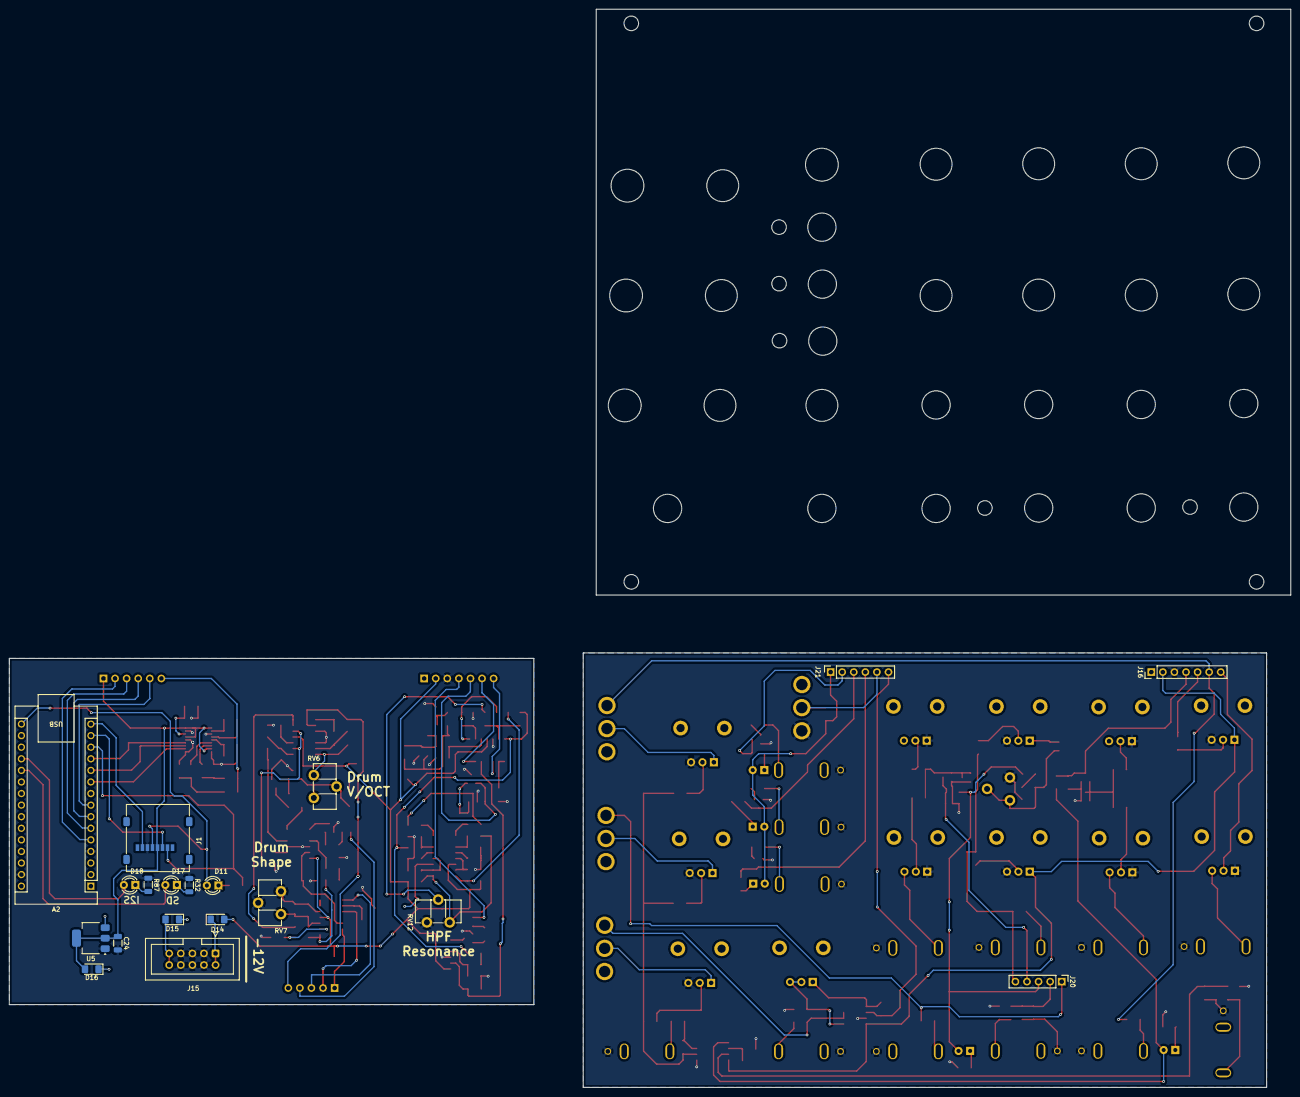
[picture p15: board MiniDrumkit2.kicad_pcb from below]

Board: 2 copper layers, 281.1 x 236.5 mm, 201 parts (19 on the bottom side), 139 nets.

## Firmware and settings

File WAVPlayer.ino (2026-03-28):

/*
WAV Files are to be in the format:Mono, 16-bit PCM encoding with 16kHz sampleRate
*/

#include <I2S.h>
#include <SD.h>
// I2S pins for Arduino Nano ESP32
#define I2S_BCLK 7  // Bit clock
#define I2S_DOUT 8  // Data out
#define I2S_LRC 9   // Left/Right clock (Word Select)

#define I2S_FAIL A2  // I2S-Initialization Fail LED
#define SD_FAIL A1   // SD-Initialization Fail LED
#define SD_CS 10

#define CH1 2   //Channel 1 Trigger Pin
#define CH2 3   //Channel 2 Trigger Pin
#define CH3 4   //Channel 3 Trigger Pin
#define PART 5  //Part Entire Pin

const int sampleRate = 16000;        // sample rate in Hz
const int bps = 16;                  // bits per sample
i2s_mode_t mode = I2S_PHILIPS_MODE;  // I2S decoder is needed

const int playersAmount = 3;
const int MAX_LENGTH = 30000;

File file;  //temporary file used to parse wav data

volatile unsigned long next;  //Time in microseconds when the next sample is set

bool anyPlaying;
int16_t mix;

hw_timer_t* timer = NULL;

byte triggerPins[playersAmount] = { CH1, CH2, CH3 };

struct Player {

  uint16_t length;
  bool playing;
  unsigned int pos;
  bool triggered;

  byte triggerPin;
  int16_t data[MAX_LENGTH];
};

Player players[playersAmount];

void setup() {
  Serial.begin(115200);
  delay(2000);

  pinMode(I2S_FAIL, OUTPUT);
  digitalWrite(I2S_FAIL, LOW);

  pinMode(CH1, INPUT_PULLUP);
  pinMode(CH2, INPUT_PULLUP);
  pinMode(CH3, INPUT_PULLUP);
  pinMode(PART, INPUT_PULLUP);

  I2S.setDataPin(I2S_DOUT);
  I2S.setFsPin(I2S_LRC);
  I2S.setSckPin(I2S_BCLK);

  Serial.println("I2S Pins set");

  if (!I2S.begin(mode, sampleRate, bps)) {
    digitalWrite(I2S_FAIL, HIGH);
    Serial.println("Failed to initialize I2S!");
    while (1)
      ;  // do nothing
  }

  pinMode(SD_FAIL, OUTPUT);
  digitalWrite(SD_FAIL, LOW);

  if (!SD.begin(SD_CS)) {
    Serial.println("Card Mount Failed");
    digitalWrite(SD_FAIL, HIGH);
    return;
  }

  Serial.println("SD card initialized");

  //Initialize Players
  for (int i = 0; i < playersAmount; i++) {
    players[i].pos = 0;
    players[i].playing = false;
    players[i].triggered = false;

    players[i].length = parseFile(i + 1, players[i].data);
    if (players[i].length > MAX_LENGTH) { players[i].length = MAX_LENGTH; }  //Limit the length of the sample

    players[i].triggerPin = triggerPins[i];
  }

  Serial.println("Wave files parsed and saved");


  Serial.println("Setup complete");
}

void loop() {

  //Check if a channel has been triggered
  checkChannelsTriggered();

  //Mix and output audio
  processAudio();

  //Check if a sample has finished playing.
  checkFinished();
}
void checkFinished() {

  for (int i = 0; i < playersAmount; i++) {
    if (players[i].pos >= players[i].length && players[i].playing) {
      Serial.print("Sample ");
      Serial.print(i + 1);
      Serial.println(" Finished");

      players[i].playing = false;
    }
  }
}

void processAudio() {

  anyPlaying = false;
  for (int i = 0; i < playersAmount; i++) {
    if (players[i].playing) {
      anyPlaying = true;  //If just one sample is playing then anyPlaying is true and the rest of the loop can be stopped
      break;
    }
  }

  if (anyPlaying) {
    //At least one player is active, mix the active samples together
    mix = 0;  //Reset mix to re-calculate the current sample

    for (int i = 0; i < playersAmount; i++) {
      if (players[i].playing) {
        mix += players[i].data[players[i].pos];  //Add the current samples together
      }
    }

    //Output the mixed sample to the Right and Left channels of the DAC
    I2S.write(mix);
    I2S.write(mix);

  } else {
    //No sample is playing, output silence
    I2S.write(0);
    I2S.write(0);
  }

  //Set the time for the next sample to be playing
  //TODO: Replace the timing with a hardware timer instead of micros()
  if (micros() > next) {
    for (int i = 0; i < playersAmount; i++) {
      if (players[i].playing) {
        players[i].pos += 1;//Set the new sample for all active players
      }
    }
    next = next + 62;
  }
}

uint16_t parseFile(int number, int16_t array[]) {
  //Write the wav-file data into the sample arrays and return the array length

  byte sizeBytes[4];
  String filename = "/";
  filename.concat(number);
  filename.concat(".wav");

  file = SD.open(filename);

  if (!file) {

    Serial.println("Could not open file");
    return 0;
  } else {
    file.seek(40);  //Skip to the size chunk

    for (int i = 0; i < 4; i++) {
      sizeBytes[i] = file.read();  //read in the 4 size bytes.
    }

    //Calculate the size of the data chunk in bytes
    uint32_t size = 0;
    size = sizeBytes[3];

    for (int i = 0; i < 3; i++) {
      size = size << 8;
      size = size | sizeBytes[2 - i];
    }
    //Calculate the number of samples (2 bytes per sample)
    int samplesAmount = size / 2;
    int toWrite = 0;  //The amount of samples to write in the array (limited by MAX_LENGTH)
    if (samplesAmount > MAX_LENGTH) {
      toWrite = MAX_LENGTH;
    } else {
      toWrite = samplesAmount;
    }

    //Write the samples to the Player arrays (Little Endian encoded! Conversion to Big endian is required)
    byte temp1 = 0;  //Temporary byte for constructing the sample value
    byte temp2 = 0;  //Temporary byte for constructing the sample value
    int16_t tempSample = 0;

    for (int i = 0; i < toWrite; i++) {
      temp1 = file.read();
      temp2 = file.read();

      tempSample = temp2;
      tempSample = tempSample << 8;
      tempSample = tempSample | temp1;

      array[i] = tempSample;
    }
    file.close();
    return samplesAmount;
  }
}

void checkChannelsTriggered() {
  for (int i = 0; i < playersAmount; i++) {

    if (digitalRead(players[i].triggerPin) == LOW && !players[i].triggered) {
      //GATE ON
      players[i].triggered = true;  // Trigger flag set, only plays the sample on the rising edge

      Serial.print("players ");
      Serial.print(i + 1);
      Serial.println(" Triggered");
      players[i].pos = 0;
      players[i].playing = true;
      next = micros() + 100;
    }

    if (digitalRead(players[i].triggerPin) == HIGH && players[i].triggered) {
      //GATE OFF
      players[i].triggered = false;  //Reset Trigger flag
      if (digitalRead(PART) == LOW) {
        players[i].playing = false;
      }
    }
  }
}

void printArray(int16_t array[], uint16_t size) {
  //Debug helper method
  Serial.print("Size: ");
  Serial.println(size);
  for (int i = 0; i < size; i++) {
    Serial.print(array[i]);
    Serial.print(" ");
    if (i % 32 == 0) {
      Serial.println(" ");
    }
  }
}
